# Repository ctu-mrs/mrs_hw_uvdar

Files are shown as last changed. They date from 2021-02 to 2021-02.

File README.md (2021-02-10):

# UVDAR Hardware
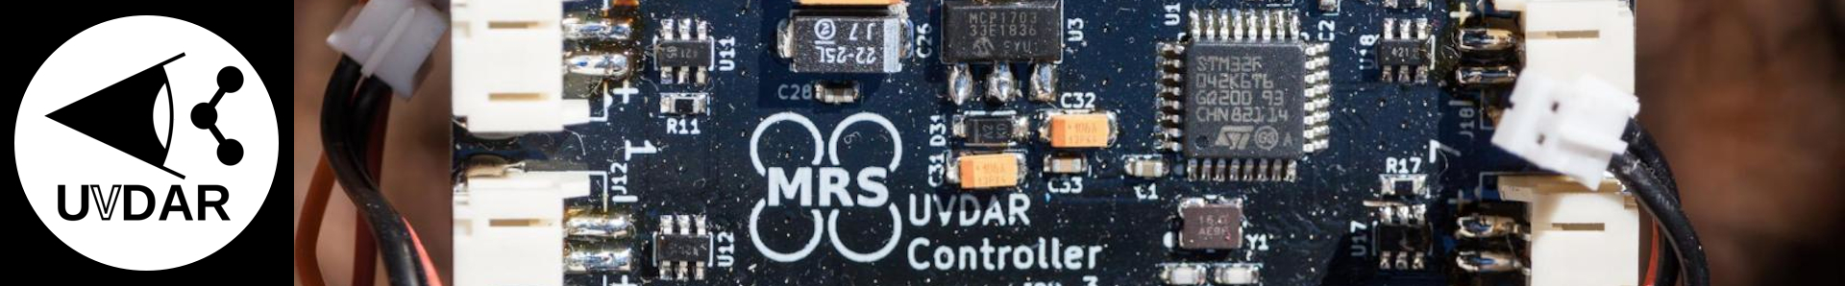
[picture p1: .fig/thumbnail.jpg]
thumbnail


## Description
This package contains hardware for UVDAR.<br>
[UVDAR](https://github.com/ctu-mrs/uvdar_core) Hardware is available in two variants: standalone and as MRS Module.<br>

The standalone variant can be connected to a computer directly using USB and is intended for quick development and trying out UVDAR.<br>
The MRS Module variant is intended to be used along with MRS Distribution Boards, namely with F450 Distribution Board as this is so far the
only Distribution board populated with a slot for a Big MRS Module.

<table>
  <tr>
    <th>
      UVDAR Standalone Variant
    </th>
    <th>
      UVDAR Module Variant
    </th>
  </tr>
  <tr>
    <td>
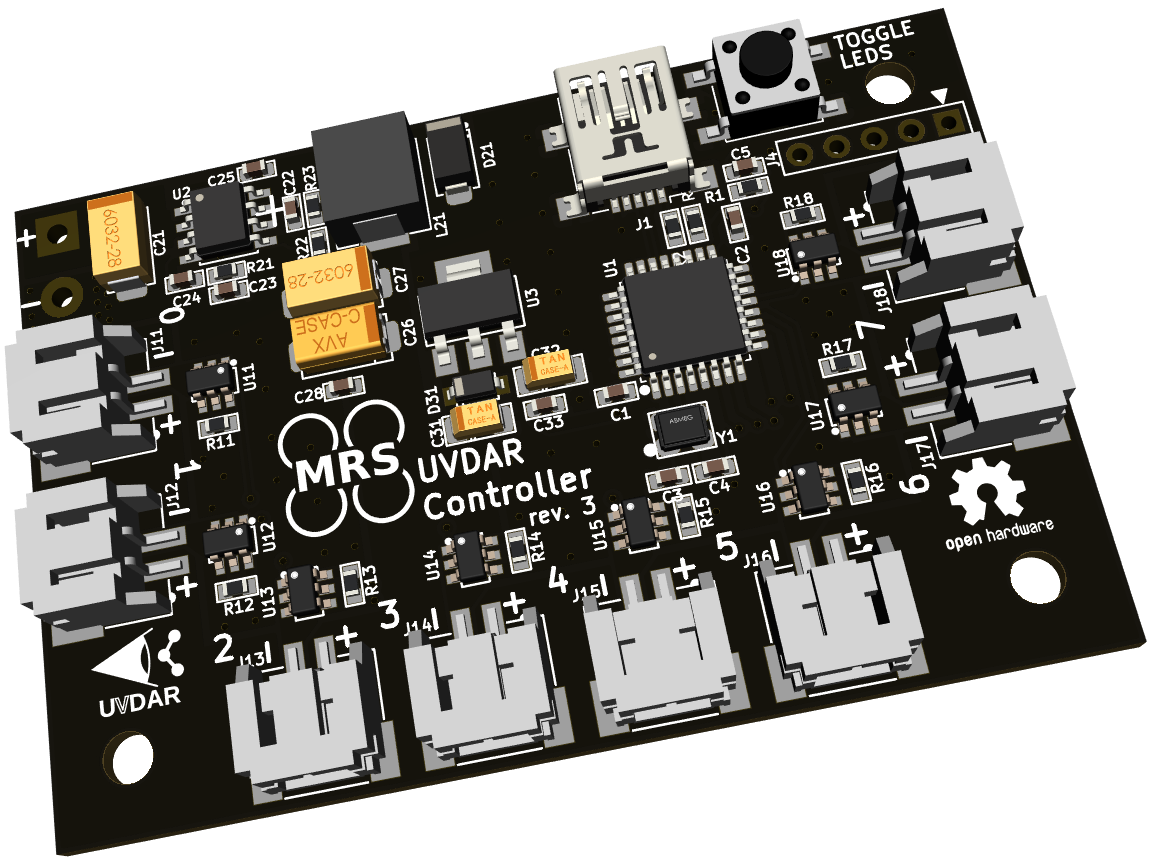
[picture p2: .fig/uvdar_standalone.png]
uvdar_standalone
      
    </td>
    <td>
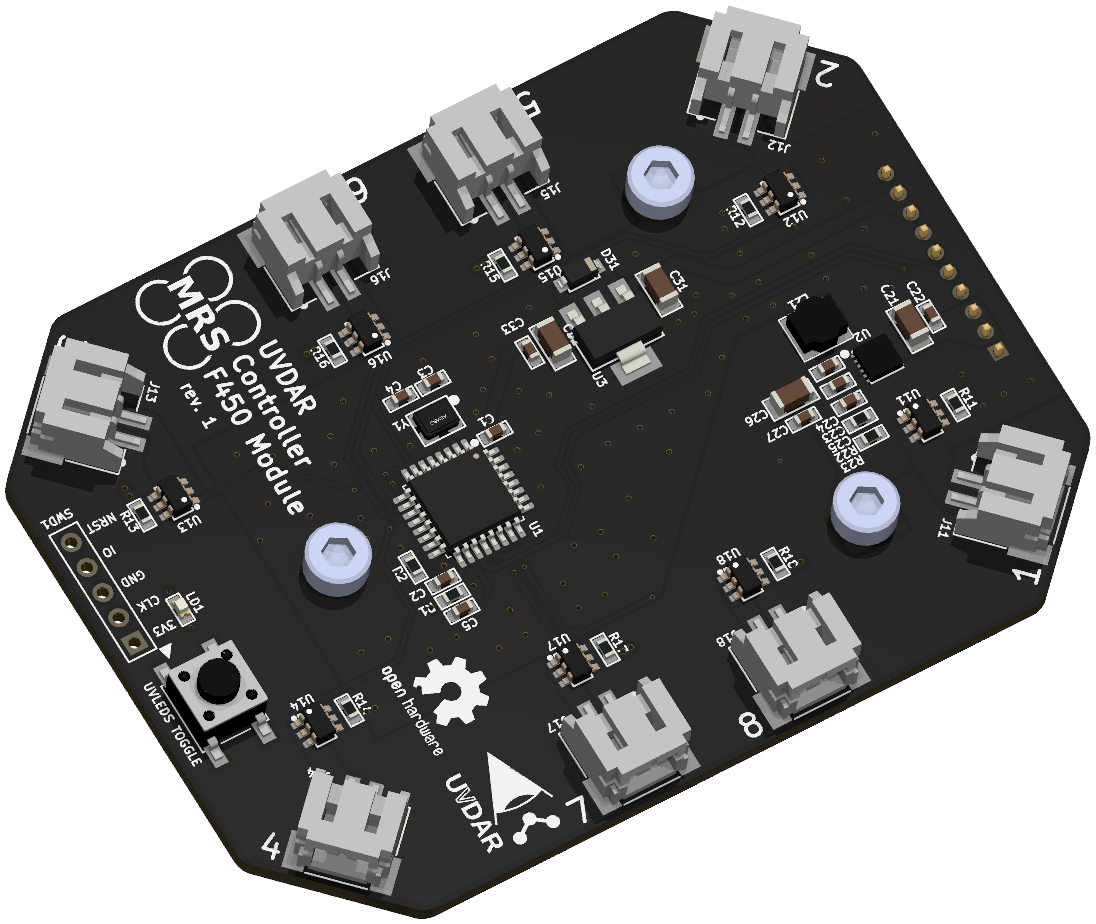
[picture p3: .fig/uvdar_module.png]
uvdar_module
      
    </td>
  </tr>
</table>

## How to use
1) Read the documentation provided with each variant.
2) Select which variant suits your needs better (note that you can use MRS Module Host Board for development with MRS Module variant).
3) Manufacture and assemble the PCB of the controller and the UV LEDs. The Gerber files as well as BOM is in the PCB folder of each variant.
4) Flash the control board with appropriate firmware using STM32CubeIDE, Atollic TrueSTUDIO, Keil uVision or STM32CubePRogrammer or any other software you like to use.
5) Connect the controller to a computer and use the [UVDAR ROS Package](https://github.com/ctu-mrs/uvdar_core).

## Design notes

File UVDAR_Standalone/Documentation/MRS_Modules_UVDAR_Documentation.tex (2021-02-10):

\documentclass[12pt, a4paper]{article}

\usepackage[export]{adjustbox}
\usepackage{fancyhdr}
\usepackage[utf8]{inputenc}
\usepackage[english]{babel}
\usepackage{longtable}
\usepackage[margin=2cm, bottom=4cm]{geometry}
\usepackage{color,soul}
\usepackage{booktabs}
\usepackage{pdfpages}

\pagestyle{fancy}
\fancyhf{}% Clear all headers/footers
\renewcommand{\headrulewidth}{.4pt}% Header rule width
\renewcommand{\footrulewidth}{0pt}% No footer rule
\fancyhead[L]{% Left header
  \rule[-1\baselineskip]{0pt}{0pt}% Strut to ensure a 1/4 \baselineskip between image and header rule
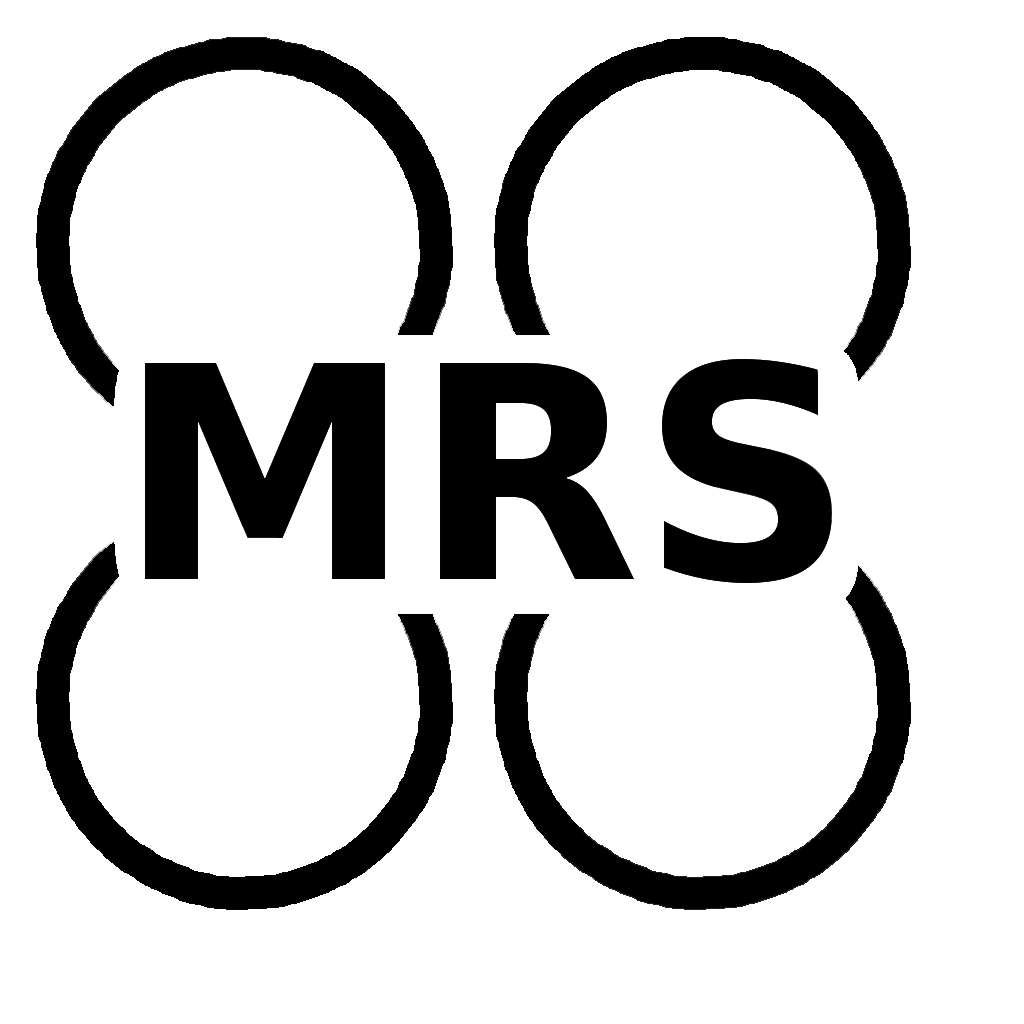
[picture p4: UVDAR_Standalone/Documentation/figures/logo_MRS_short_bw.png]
  % Image
  \quad% Space
}

\fancyhead[R]{
STANDALONE UVDAR CONTROLLER
}

\chead{\thepage}

\title{
\Huge{STANDALONE UVDAR CONTROLLER}\\
REVISION 3\\
\vspace{0.5cm}
\LARGE{David Zaitlik}\\
\vspace{0.5cm}
\normalsize{\textit{Multi-Robot Systems Group, FEE CTU in Prague}}\\
\vspace{1.5cm}
\vfill
\begin{figure}[h]
\centering
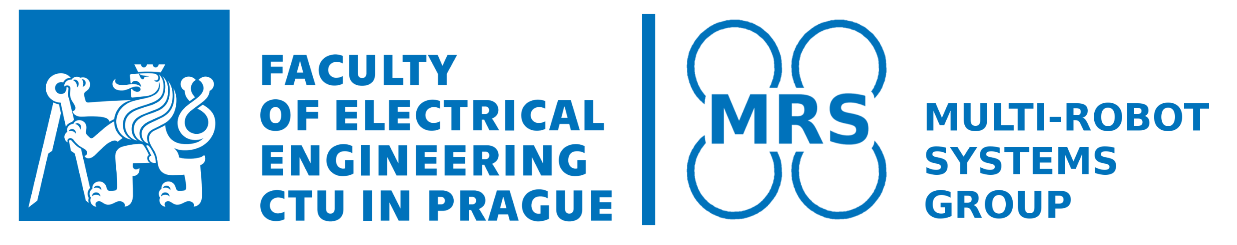
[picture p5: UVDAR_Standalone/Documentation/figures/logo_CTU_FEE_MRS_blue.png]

\end{figure}
\date{\today}

}

\setlength{\headheight}{3.5\baselineskip}% To accommodate new oversized header

\begin{document}
\clearpage
\maketitle
\thispagestyle{empty}

\pagebreak
\tableofcontents
\listoffigures
\listoftables
\thispagestyle{empty}

\pagebreak
\setcounter{page}{1}
\pagenumbering{arabic}
\section{Introduction}
UVDAR is a system for mutual UAV localization using Ultra-Violet LED blinkers.\\
\\
This PCB is a standalone UVDAR controller designed for simple development of the UVDAR system.\\
\\
The controller communicates using USB. The power for the PCB is provided by the \verb|J3| connector.\\
\\
The Board is designed to work with high-power UVLEDs ProLight Opto PM2B-1LLE, however any other similar UVLED can be used.\\
\begin{figure}[h]
\centering

\caption{STANDALONE UVDAR CONTROLLER: Thumbnail}
\label{fig:thumbnail}
\end{figure}

\pagebreak
\subsection{Default Configuration}
The default configuration used by the MRS Group drives two UVLEDs ProLight Opto PM2B-1LLE per channel. These UVLEDs are soldered to a PCB which acts as a heatsink and mounting point to the end of the drone arm. The UVLEDs are at a right angle, which can be seen in figure \ref{fig:f450_with_uvdar}.\\\
\\
The voltage for UVLEDs is set to 8V, but this can be easily changed by adjusting the value of $R_{22}$ resistor according to the following formula:\\
$R_{22} = 22.1 \cdot \left(V_{OUT} - 1 \right) \left[ k\Omega \right]$
\\
The UVLEDs are driven using constant-current controllers that are set to approximately to 85mA. This value can be modified by changing the value of resistors $R_{11} - R_{18}$ according to the BCR421UW6 driver datasheet.\\
\\
Channels 1-4 are used to drive the UVLEDs on the arms and channels 5-8 are used to drive the beacon UVLEDs on the top of the drone.

\begin{figure}[h]
\centering
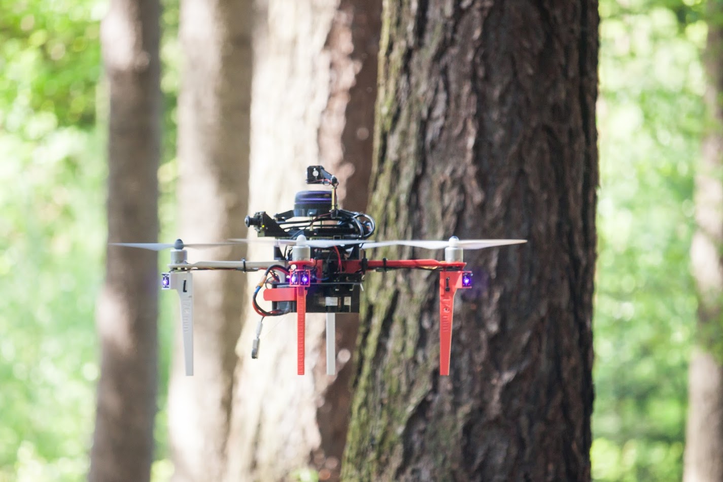
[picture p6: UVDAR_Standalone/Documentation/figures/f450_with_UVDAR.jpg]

\caption{STANDALONE UVDAR CONTROLLER: Photo of an F450 drone with UVDAR}
\label{fig:f450_with_uvdar}
\end{figure}

\pagebreak
\section{Dimensions}
The Board is 67mm long and 45mm wide with three M3 mounting holes.\\
\\
The mechanical drawing can be seen in Figure \ref{fig:dimensions} below.

\begin{figure}[h]
\centering

\caption{STANDALONE UVDAR CONTROLLER: Dimensions}
\label{fig:dimensions}
\end{figure}

\pagebreak
\section{Connectors}
The Board has 8 connectors numbered from 1 to 8 to connect UVLEDs. The pinout of these connectors is described in \verb|UVLED|.\\
The board has a connector for connecting to a Distribution Board with a standard pinout as seen in \verb|MRS MODULE|.\\
The last connector is the Serial Wire Debug (\verb|SWD|) connector for programming the on-board STM32F042K6T.
The connector placement can be seen in figures \ref{fig:connectors_top} and \ref{fig:connectors_bot}.
\subsection{Connector Placement Drawing}
\begin{figure}[h]
\centering

\caption{STANDALONE UVDAR CONTROLLER: Connectors Placement, Top Layer}
\label{fig:connectors_top}
\end{figure}

\pagebreak
\subsection{Connector Pinouts}
\begin{center}
\begin{minipage}[t][3cm][t]{0.24\textwidth}
\centering
\begin{tabular}{|l|l|}
\hline
\multicolumn{2}{|p{2cm}|}{\centering\textbf{UVLED}} \\ \hline
1               & LED ANODE                \\ \hline
2               & LED KATHODE                \\ \hline
\end{tabular}
\end{minipage}
\begin{minipage}[t][3cm][t]{0.24\textwidth}
\centering
\begin{tabular}{|l|l|}
\hline
\multicolumn{2}{|p{2cm}|}{\centering\textbf{BAT IN}} \\ \hline
1               & BAT+                \\ \hline
2               & BAT-                 \\ \hline
\end{tabular}
\end{minipage}

\begin{minipage}[t][3.5cm][t]{0.24\textwidth}
\centering
\begin{tabular}{|l|l|}
\hline
\multicolumn{2}{|p{3cm}|}{\centering\textbf{USB}} \\ \hline
1               & VUSB         \\ \hline
2               & D-        \\ \hline
3               & D+        \\ \hline
4               & NC         \\ \hline
5               & GND     \\ \hline
\end{tabular}
\end{minipage}
\begin{minipage}[t][3cm][t]{0.24\textwidth}
\centering
\begin{tabular}{|l|l|}
\hline
\multicolumn{2}{|p{2cm}|}{\centering\textbf{SWD}} \\ \hline
1               & 3V3               \\ \hline
2               & SWCLK             \\ \hline
3               & GND               \\ \hline
4               & SWDIO             \\ \hline
5               & NRST              \\ \hline
\end{tabular}
\hfill
\end{minipage}

\begin{minipage}[t][3.5cm][t]{0.24\textwidth}
\centering
\begin{tabular}{|l|l|}
\hline
\multicolumn{2}{|p{3cm}|}{\centering\textbf{MRS MODULE}} \\ \hline
1               & GND         \\ \hline
2               & VBAT        \\ \hline
3               & VBAT        \\ \hline
4               & GND         \\ \hline
5               & UART\verb|_|TX     \\ \hline
6               & UART\verb|_|RX     \\ \hline
7               & GND         \\ \hline
8               & 5V          \\ \hline
9               & 5V          \\ \hline
10              & GND         \\ \hline
\end{tabular}
\end{minipage}
\end{center}

\pagebreak
\section{MCU Firmware}

The firmware receives data using USB; the data are in the \verb|baca_protocol| format used by the \verb|mrs_serial| node.\\
The button on the PCB serves to "mute" the UVLEDs. This button toggles global enable flag in order to stop the blinking, but does not change any other settings and does not stop the counter. This flag can be set using the UART as well.\\
\\
All setting are stored in the internal FLASH memory and are retrieved on startup.\\
\\
The byte structure of the \verb|baca_protocol| can be seen in table \ref{tab:baca_protocol_table}.
The message starts with letter 'b' (0x62 in hex) and is followed by the length of the payload (1-255).
The payload then follows. The first byte of the payload is the \verb|Message ID| and the rest of the payload contains the data (if any). The last byte is the checksum which is a simple sum of all previous bytes.\\
\\
Several message types have been implemented to control the board.

\begin{table}[h]
\begin{tabular}{|c|c|c|c|c|c|}
\hline
\textbf{Byte}   & 0          & 1                     & 2 ... (n-1) & n        \\ \hline
\textbf{Value} & 'b' (0x62) & Length of the payload & Payload (Message ID and Data)       & Checksum \\ \hline
\end{tabular}
\caption{STANDALONE UVDAR CONTROLLER: Baca Protocol Message}
\label{tab:baca_protocol_table}
\end{table}

\subsection{Message Types}
The available messages are described below:\\
\begin{itemize}
\item \textbf{Global Enable LEDs} - This is a software version of the HW switch on the PCB - This overrides, but saves all configuration and turns off all UVLEDs, or resumes the original settings.\\
\begin{flushleft}
\begin{tabular}{|l|}
\hline
Command Byte: 0x90													\\ \hline
Payload Size: 0														\\ \hline
\end{tabular}
\end{flushleft}

\item \textbf{Bulk Enable LEDs} - Enables or Disables the UVLED with the same index as the payload Byte. This will reset counters of all LEDs.\\
\begin{flushleft}
\begin{tabular}{|l|}
\hline
Command Byte: 0x91													\\ \hline
Payload size: 8 B													\\ \hline
Payload Bytes: 0x00 (UVLED Disabled), 0x01 (UVLED Enabled)			\\ \hline
Payload Byte 0: UVLED1 enabled =  0x00 (Disabled), 0x01 (Enabled)	\\ \hline
Payload Byte 1: UVLED2 enabled =  0x00 (Disabled), 0x01 (Enabled)	\\ \hline
Payload Byte 2: UVLED3 enabled =  0x00 (Disabled), 0x01 (Enabled)	\\ \hline
Payload Byte 3: UVLED4 enabled =  0x00 (Disabled), 0x01 (Enabled)	\\ \hline
Payload Byte 4: UVLED5 enabled =  0x00 (Disabled), 0x01 (Enabled)	\\ \hline
Payload Byte 5: UVLED6 enabled =  0x00 (Disabled), 0x01 (Enabled)	\\ \hline
Payload Byte 6: UVLED7 enabled =  0x00 (Disabled), 0x01 (Enabled)	\\ \hline
Payload Byte 7: UVLED8 enabled =  0x00 (Disabled), 0x01 (Enabled)	\\ \hline
\end{tabular}
\end{flushleft}

\item \textbf{Bulk Set Periods} - Sets blinking freqeuncy of the LED with the same index as the payload Byte. This will reset counters of all LEDs.\\
\begin{flushleft}
\begin{tabular}{|l|}
\hline
Command Byte: 0x92													\\ \hline
Payload size: 8 B													\\ \hline
Payload Byte 0: Desired frequency of the UVLED1						\\ \hline
Payload Byte 1: Desired frequency of the UVLED2						\\ \hline
Payload Byte 2: Desired frequency of the UVLED3						\\ \hline
Payload Byte 3: Desired frequency of the UVLED4						\\ \hline
Payload Byte 4: Desired frequency of the UVLED5						\\ \hline
Payload Byte 5: Desired frequency of the UVLED6						\\ \hline
Payload Byte 6: Desired frequency of the UVLED7						\\ \hline
Payload Byte 7: Desired frequency of the UVLED8						\\ \hline
\end{tabular}
\end{flushleft}

\item \textbf{Enable LED} - enables the UVLED with the specified index. This will reset the counter of the specified UVLED.\\
\begin{flushleft}
\begin{tabular}{|l|}
\hline
Command Byte: 0x93													\\ \hline
Payload Size: 2														\\ \hline
Payload Byte 0: UVLED index (0-7)									\\ \hline
Payload Byte 1: 0x00 (Disabled), 0x01 (Enabled)						\\ \hline
\end{tabular}
\end{flushleft}

\item \textbf{Set Period} - Sets blinking frequency of the UVLED with the specified index. This will reset the counter of the specified UVLED.\\
\begin{flushleft}
\begin{tabular}{|l|}
\hline
Command Byte: 0x94													\\ \hline
Payload Size: 2														\\ \hline
Payload Byte 0: LED index (0-7)										\\ \hline
Payload Byte 1: Desired frequency of the UVLED						\\ \hline
\end{tabular}
\end{flushleft}

\item \textbf{Get Enabled} - Returns 8 bytes. These bytes indicate if the UVLEDs are enabled or disabled.\\
\begin{flushleft}
\begin{tabular}{|l|}
\hline
Command Byte: 0x95															\\ \hline
Payload Size: 0																\\ \hline
Return Payload Size: 8														\\ \hline
Return Payload Byte 0: UVLED1 enabled =  0x00 (Disabled), 0x01 (Enabled)	\\ \hline
Return Payload Byte 1: UVLED2 enabled =  0x00 (Disabled), 0x01 (Enabled)	\\ \hline
Return Payload Byte 2: UVLED3 enabled =  0x00 (Disabled), 0x01 (Enabled)	\\ \hline
Return Payload Byte 3: UVLED4 enabled =  0x00 (Disabled), 0x01 (Enabled)	\\ \hline
Return Payload Byte 4: UVLED5 enabled =  0x00 (Disabled), 0x01 (Enabled)	\\ \hline
Return Payload Byte 5: UVLED6 enabled =  0x00 (Disabled), 0x01 (Enabled)	\\ \hline
Return Payload Byte 6: UVLED7 enabled =  0x00 (Disabled), 0x01 (Enabled)	\\ \hline
Return Payload Byte 7: UVLED8 enabled =  0x00 (Disabled), 0x01 (Enabled)	\\ \hline
\end{tabular}
\end{flushleft}

\item \textbf{Get Periods} - Returns 8 bytes. These bytes represent the frequency of the UVLEDs.\\
\begin{flushleft}
\begin{tabular}{|l|}
\hline
Command Byte: 0x96														\\ \hline
Payload Size: 0															\\ \hline
Return Payload Size: 8													\\ \hline
Return Payload Byte 0: UVLED1 Frequency									\\ \hline
Return Payload Byte 1: UVLED2 Frequency									\\ \hline
Return Payload Byte 2: UVLED3 Frequency									\\ \hline
Return Payload Byte 3: UVLED4 Frequency									\\ \hline
Return Payload Byte 4: UVLED5 Frequency									\\ \hline
Return Payload Byte 5: UVLED6 Frequency									\\ \hline
Return Payload Byte 6: UVLED7 Frequency									\\ \hline
Return Payload Byte 7: UVLED8 Frequency									\\ \hline
\end{tabular}
\end{flushleft}
\end{itemize}
\pagebreak
\subsection{Implementation notes}
The Board is equipped with the STM32F042K6T6 microcontroller. Its firmware is programmed using STM32Cube Hardware Abstraction Layer Libraries.\\
The pinout of the MCU can be seen in the Figure \ref{fig:ph_mcu_pinout}.\\
\begin{figure}[h]
\centering
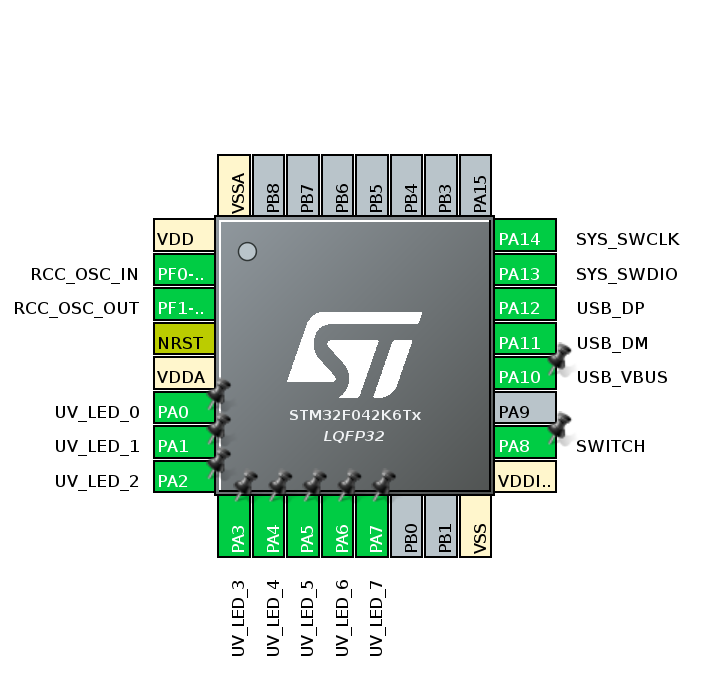
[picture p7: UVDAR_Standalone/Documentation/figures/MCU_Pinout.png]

\caption{STANDALONE UVDAR CONTROLLER: MCU pinout}
\label{fig:mcu_pinout}
\end{figure}
The firmware is written with the need for versatility in mind and therefore is not optimal for specialised applications. The UVLED blinking is implemented using software PWM which allows us to change frequencies of individual channels, as is desired for research purposes. I suggest using hardware PWMs if the UVLEDs will have the same frequency. This is achievable only for UVLEDs 1 to 4 since these are connected to TIM2 channels 1 to 4. The other UVLED channels were moved to arbitrary pins for easier routing in the beginning and were left for legacy purposes. If hardware PWM for all channels is desired, then rearanging UVLEDs is necessary.

\pagebreak
\subsection{Software PWM for UVLEDs}
The UVLED blinking is implemented in \verb|uv_led_driver.c/h| files. To function properly, the pins must be named as \verb|UV_LED_x| where \verb|x| is a number between 0 and 8. This may of course be be changed by the programmer. These pins are used in the \verb|uv_led_init( void )| function to map them to an internally used array. This function also reads the frequency values and flags for enabling UVLEDs from the internal FLASH and resets the counters.\\
\\
The \verb|uv_led_set_frequency(uint8_t led_id, uint8_t frequency)| function sets the frequency of the selected UVLED. The input argument \verb|led_id| is index of the UVLED to be set starting from 0 and the \verb|frequency| is an integer value of desired frequency in range 1 to 60 Hz.\\
This function then calculates the number of ticks of the counter needed to toggle the LED (half of its total period). To calculate this value properly, the value of \verb|TIMER_FREQ| must be set to the frequency of the hardware timer used to increment the counter.\\
The calculated value is then saved to the internal FLASH.\\
\\
The \verb|uv_led_enable(uint8_t led_id, uint8_t enable)| function sets the enable flag of the selected UVLED. The input argument \verb|led_id| is index of the UVLED to be set starting from 0, with \verb|enable| as an integer of value 1 (true) or 0(false). Any other values are invalid.\\
The enable flag is then saved to the internal FLASH.\\
\\
The \verb|uv_led_toggle(uint8_t led_id)| function toggles the selected UVLED. The input argument \verb|led_id| is index of the UVLED to be set starting from 0.\\
This function is called if the counter value reaches the desired value. This is managed using the Timer Period Elapsed Callback Function \verb|HAL_TIM_PeriodElapsedCallback| where the counter is increased everytime the used timer's period elapses. The used timer in this appliation is \verb|TIM3| with a frequency of 10kHz.
\subsubsection{Global Enable Flag}
To be able to disable all UVLEDs on a button switch without affecting anything else, a simple flag was created. This flag toggles on with a button press (\verb|SWITCH|) or with receiving a global enable message using UART. This flag is used in the \verb|uv_led_toggle(uint8_t led_id)|.

\subsection{USB implementation}
TODO: Rewrite to USB
The USB communication using the STM Middleware. The message is processed in \verb|CDC_Receive_FS| function in \verb|usbd_cdc_if.c| file. If the message has the correct format (if the checksum is correct and has one of the valid message IDs), the apropriate function is called.\\
\\ VBUS Sensing has not yet been implemented.
\pagebreak

\newgeometry{left=1cm,right=1cm}
\section{Bill Of Materials and Assembly Drawings}
\begin{longtable}{|p{5cm}|p{5cm}|p{5cm}|p{1.7cm}|}
\hline
\textbf{References} & \textbf{Value} & \textbf{Footprint} & \textbf{Quantity}\\ \hline
C2, C5, C25, C33                       & 0.1uF                   & C0603                                      & 4        \\ \hline
C3, C4, C22                            & 10pF                    & C0603                                      & 3        \\ \hline
C1, C28                                & 1uF                     & C0603                                      & 2        \\ \hline
C23                                    & 1nF                     & C0603                                      & 1        \\ \hline
C24                                    & 10nF                    & C0603                                      & 1        \\ \hline
C31, C32                               & 10uF                    & CTAN1206                                   & 2        \\ \hline
C26                                    & 100uF/10V               & CTAN2312                                   & 1        \\ \hline
C21, C27                               & 22uF/25V                & CTAN2412                                   & 2        \\ \hline
R11, R12, R13, R14, R15, R16, R17, R18 & 3R3-0.5\%               & R0603                                      & 8        \\ \hline
R1, R2, R3, R22                        & 10k                     & R0603                                      & 4        \\ \hline
R21                                    & 27k4                    & R0603                                      & 1        \\ \hline
R23                                    & 1k1                     & R0603                                      & 1        \\ \hline
L21                                    & SRP6540-8R2M            & L\_SRP6540                                 & 1        \\ \hline
D21                                    & B340A                   & D\_SMA                                     & 1        \\ \hline
D31                                    & 1N4148W-E3-08           & SOD-123                                    & 1        \\ \hline
U1                                     & STM32F042K6T6           & LQFP-32\_7x7mm\_P0.8mm                     & 1        \\ \hline
U2                                     & TPS54331DR              & SOIC-8                                     & 1        \\ \hline
U3                                     & MCP1703-3302E           & SOT-223-3(TAB-pin-2)                       & 1        \\ \hline
U11, U12, U13, U14, U15, U16, U17, U18 & BCR421UW6               & SOT-26-6                                   & 8        \\ \hline
Y1                                     & ABM8G                   & ABM8G                                      & 1        \\ \hline
SW1                                    & Push-Switch\_SMT\_6x6mm & Tactile\_Switch\_6x6\_SMT                  & 1        \\ \hline
J4                                     & SWO                     & Header\_1x05\_P2.54mm                      & 1        \\ \hline
J11, J12, J13, J14, J15, J16, J17, J18 & JST-PH\_2               & JST\_PH\_2                                 & 8        \\ \hline
J1                                     & USB\_B\_Mini            & USB\_Mini-B\_Lumberg\_2486\_01\_Horizontal & 1        \\ \hline

\caption{STANDALONE UVDAR CONTROLLER: Bill Of Materials}
\label{tab:bom}
\end{longtable}
\vfill
\restoregeometry

\pagebreak
% change scale and angle accordingly
\includepdf[pages=-, scale=0.8, angle=270, pagecommand={}]{figures/Assembly_top.pdf}

\pagebreak
\section{Schematic}


\end{document}

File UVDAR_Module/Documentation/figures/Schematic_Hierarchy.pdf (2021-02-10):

MAIN SHEET

Sheet 1

BUCK 8V

Sheet 2

8V

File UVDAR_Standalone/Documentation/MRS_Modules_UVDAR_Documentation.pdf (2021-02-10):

# STANDALONE UVDAR CONTROLLER REVISION 3

# David Zaitlik

Multi-Robot Systems Group, FEE CTU in Prague

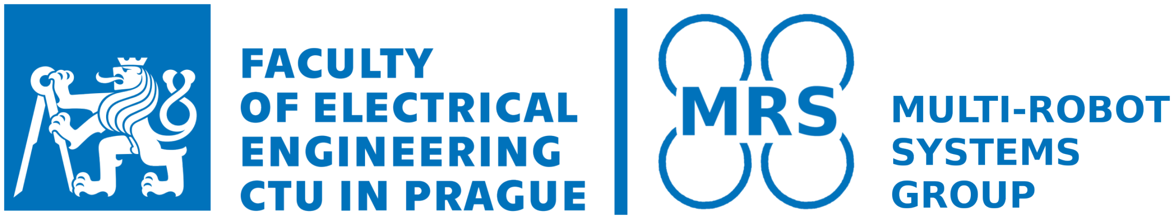
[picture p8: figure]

### February 10, 2021

## Contents

1 Introduction | 1
1.1 Default Configuration | | 2
2 Dimensions | 3
3 Connectors | 4
3.1 Connector Placement Drawing | | 4
3.2 Connector Pinouts | | 5
4 MCU Firmware | 6
4.1 Message Types | | 6
4.2 Implementation notes | | 9
4.3 Software PWM for UVLEDs | 10
4.3.1 Global Enable Flag | 10
4.4 USB implementation | 10
5 Bill Of Materials and Assembly Drawings | 11
6 Schematic | 13

## List of Figures

1 | STANDALONE UVDAR CONTROLLER: Thumbnail | | 1
2 | STANDALONE UVDAR CONTROLLER: Photo of an F450 drone with UVDAR 2
3 | STANDALONE UVDAR CONTROLLER: Dimensions | | 3
4 | STANDALONE UVDAR CONTROLLER: Connectors Placement, Top Layer . . | 4
5 | STANDALONE UVDAR CONTROLLER: MCU pinout | | 9

## List of Tables

1 | STANDALONE UVDAR CONTROLLER: Baca Protocol Message | | 6
2 | STANDALONE UVDAR CONTROLLER: Bill Of Materials | 11

1 STANDALONE UVDAR CONTROLLER

## 1 Introduction

UVDAR is a system for mutual UAV localization using Ultra-Violet LED blinkers.

This PCB is a standalone UVDAR controller designed for simple development of the UVDAR system.

The controller communicates using USB. The power for the PCB is provided by the J3 connector.

The Board is designed to work with high-power UVLEDs ProLight Opto PM2B-1LLE, however any other similar UVLED can be used.

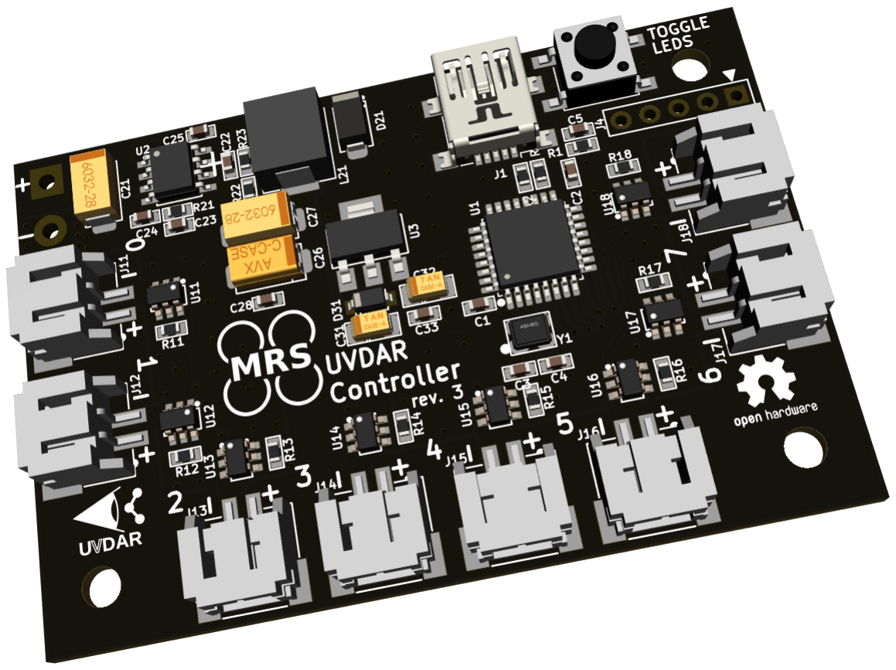
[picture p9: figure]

Figure 1: STANDALONE UVDAR CONTROLLER: Thumbnail

### 1.1 Default Configuration

The default configuration used by the MRS Group drives two UVLEDs ProLight Opto PM2B-1LLE per channel. These UVLEDs are soldered to a PCB which acts as a heatsink and mounting point to the end of the drone arm. The UVLEDs are at a right angle, which can be seen in figure 2.

The voltage for UVLEDs is set to 8V, but this can be easily changed by adjusting the value of R22 resistor according to the following formula:
R22 = 22.1 · (VOUT − 1) [kΩ]
The UVLEDs are driven using constant-current controllers that are set to approximately to 85mA. This value can be modified by changing the value of resistors R11 − R18 according to the BCR421UW6 driver datasheet.

Channels 1-4 are used to drive the UVLEDs on the arms and channels 5-8 are used to drive the beacon UVLEDs on the top of the drone.


Figure 2: STANDALONE UVDAR CONTROLLER: Photo of an F450 drone with UVDAR

## 2 Dimensions

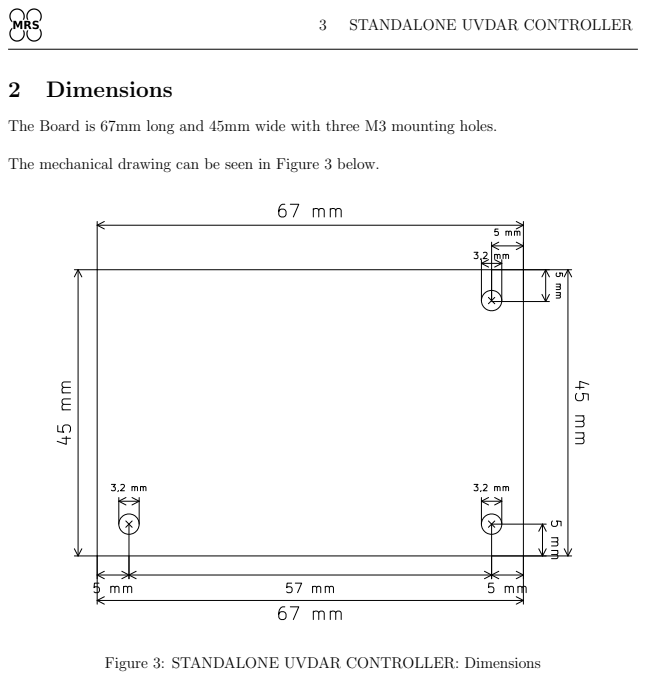
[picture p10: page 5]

The Board is 67mm long and 45mm wide with three M3 mounting holes.

The mechanical drawing can be seen in Figure 3 below.

Figure 3: STANDALONE UVDAR CONTROLLER: Dimensions

## 3 Connectors

The Board has 8 connectors numbered from 1 to 8 to connect UVLEDs. The pinout of these connectors is described in UVLED.
The board has a connector for connecting to a Distribution Board with a standard pinout as seen in MRS MODULE.
The last connector is the Serial Wire Debug (SWD) connector for programming the on-board STM32F042K6T. The connector placement can be seen in figures 4 and ??.

### 3.1 Connector Placement Drawing

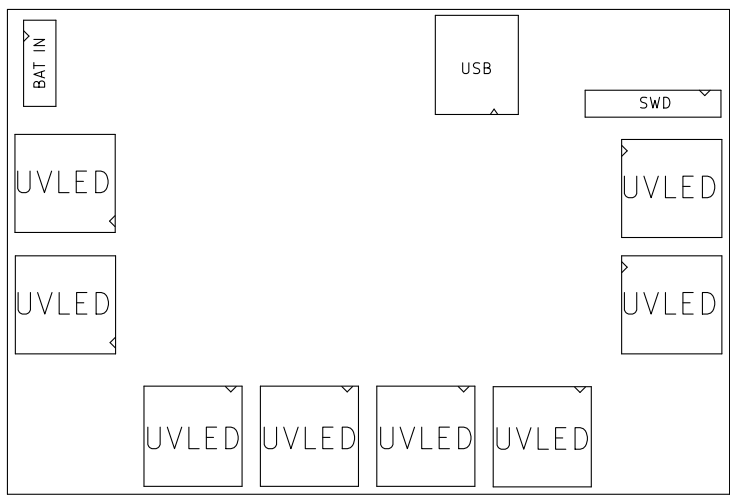
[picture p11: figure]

Figure 4: STANDALONE UVDAR CONTROLLER: Connectors Placement, Top Layer

### 3.2 Connector Pinouts

UVLED
1 | LED ANODE
2 | LED KATHODE

BAT IN
1 | BAT+
2 | BAT-

USB
1 | VUSB
2 | D-
3 | D+
4 | NC
5 | GND

SWD
1 | 3V3
2 | SWCLK
3 | GND
4 | SWDIO
5 | NRST

MRS
MODULE
1 | GND
2 | VBAT
3 | VBAT
4 | GND
5 | UART_TX
6 | UART_RX
7 | GND
8 | 5V
9 | 5V
10 | GND

## 4 MCU Firmware

The firmware receives data using USB; the data are in the baca_protocol format used by the mrs_serial node.
The button on the PCB serves to ”mute” the UVLEDs. This button toggles global enable flag in order to stop the blinking, but does not change any other settings and does not stop the counter. This flag can be set using the UART as well.

All setting are stored in the internal FLASH memory and are retrieved on startup.

The byte structure of the baca_protocol can be seen in table 1. The message starts with letter ’b’ (0x62 in hex) and is followed by the length of the payload (1-255). The payload then follows. The first byte of the payload is the Message ID and the rest of the payload contains the data (if any). The last byte is the checksum which is a simple sum of all previous bytes.

Several message types have been implemented to control the board.

Byte | 0 | 1 | 2 ... (n-1) | n
Value | ’b’ (0x62) | Length of the payload | Payload (Message ID and Data) | Checksum

Table 1: STANDALONE UVDAR CONTROLLER: Baca Protocol Message

### 4.1 Message Types

The available messages are described below:

Global Enable LEDs - This is a software version of the HW switch on the PCB - This overrides, but saves all configuration and turns off all UVLEDs, or resumes the original settings.

Command Byte: 0x90
Payload Size: 0

Bulk Enable LEDs - Enables or Disables the UVLED with the same index as the pay- load Byte. This will reset counters of all LEDs.

Command Byte: 0x91
Payload size: 8 B
Payload Bytes: 0x00 (UVLED Disabled), 0x01 (UVLED Enabled) Payload Byte 0: UVLED1 enabled = 0x00 (Disabled), 0x01 (Enabled) Payload Byte 1: UVLED2 enabled = 0x00 (Disabled), 0x01 (Enabled) Payload Byte 2: UVLED3 enabled = 0x00 (Disabled), 0x01 (Enabled) Payload Byte 3: UVLED4 enabled = 0x00 (Disabled), 0x01 (Enabled) Payload Byte 4: UVLED5 enabled = 0x00 (Disabled), 0x01 (Enabled) Payload Byte 5: UVLED6 enabled = 0x00 (Disabled), 0x01 (Enabled) Payload Byte 6: UVLED7 enabled = 0x00 (Disabled), 0x01 (Enabled)
Payload Byte 7: UVLED8 enabled = 0x00 (Disabled), 0x01 (Enabled)

Bulk Set Periods - Sets blinking freqeuncy of the LED with the same index as the payload Byte. This will reset counters of all LEDs.

Command Byte: 0x92
Payload size: 8 B
Payload Byte 0: Desired frequency of the UVLED1 Payload Byte 1: Desired frequency of the UVLED2 Payload Byte 2: Desired frequency of the UVLED3 Payload Byte 3: Desired frequency of the UVLED4 Payload Byte 4: Desired frequency of the UVLED5 Payload Byte 5: Desired frequency of the UVLED6 Payload Byte 6: Desired frequency of the UVLED7
Payload Byte 7: Desired frequency of the UVLED8

Enable LED - enables the UVLED with the specified index. This will reset the counter of the specified UVLED.

Command Byte: 0x93
Payload Size: 2
Payload Byte 0: UVLED index (0-7)
Payload Byte 1: 0x00 (Disabled), 0x01 (Enabled)

Set Period - Sets blinking frequency of the UVLED with the specified index. This will reset the counter of the specified UVLED.

Command Byte: 0x94
Payload Size: 2
Payload Byte 0: LED index (0-7)
Payload Byte 1: Desired frequency of the UVLED

Get Enabled - Returns 8 bytes. These bytes indicate if the UVLEDs are enabled or disabled.

Command Byte: 0x95
Payload Size: 0
Return Payload Size: 8
Return Payload Byte 0: UVLED1 enabled = 0x00 (Disabled), 0x01 (Enabled) Return Payload Byte 1: UVLED2 enabled = 0x00 (Disabled), 0x01 (Enabled) Return Payload Byte 2: UVLED3 enabled = 0x00 (Disabled), 0x01 (Enabled) Return Payload Byte 3: UVLED4 enabled = 0x00 (Disabled), 0x01 (Enabled) Return Payload Byte 4: UVLED5 enabled = 0x00 (Disabled), 0x01 (Enabled) Return Payload Byte 5: UVLED6 enabled = 0x00 (Disabled), 0x01 (Enabled) Return Payload Byte 6: UVLED7 enabled = 0x00 (Disabled), 0x01 (Enabled) Return Payload Byte 7: UVLED8 enabled = 0x00 (Disabled), 0x01 (Enabled)

Get Periods - Returns 8 bytes. These bytes represent the frequency of the UVLEDs.

Command Byte: 0x96
Payload Size: 0
Return Payload Size: 8
Return Payload Byte 0: UVLED1 Frequency Return Payload Byte 1: UVLED2 Frequency Return Payload Byte 2: UVLED3 Frequency Return Payload Byte 3: UVLED4 Frequency Return Payload Byte 4: UVLED5 Frequency Return Payload Byte 5: UVLED6 Frequency Return Payload Byte 6: UVLED7 Frequency Return Payload Byte 7: UVLED8 Frequency

### 4.2 Implementation notes

The Board is equipped with the STM32F042K6T6 microcontroller. Its firmware is programmed using STM32Cube Hardware Abstraction Layer Libraries.
The pinout of the MCU can be seen in the Figure ??.
The firmware is written with the need for versatility in mind and therefore is not optimal


Figure 5: STANDALONE UVDAR CONTROLLER: MCU pinout

for specialised applications. The UVLED blinking is implemented using software PWM which allows us to change frequencies of individual channels, as is desired for research purposes. I suggest using hardware PWMs if the UVLEDs will have the same frequency. This is achievable only for UVLEDs 1 to 4 since these are connected to TIM2 channels 1 to 4. The other UVLED channels were moved to arbitrary pins for easier routing in the beginning and were left for legacy purposes. If hardware PWM for all channels is desired, then rearanging UVLEDs is necessary.

### 4.3 Software PWM for UVLEDs

The UVLED blinking is implemented in uv_led_driver.c/h files. To function properly, the pins must be named as UV_LED_x where x is a number between 0 and 8. This may of course be be changed by the programmer. These pins are used in the uv_led_init( void ) function to map them to an internally used array. This function also reads the frequency values and flags for enabling UVLEDs from the internal FLASH and resets the counters.

The uv_led_set_frequency(uint8_t led_id, uint8_t frequency) function sets the frequency of the selected UVLED. The input argument led_id is index of the UVLED to be set starting from 0 and the frequency is an integer value of desired frequency in range 1 to 60 Hz. This function then calculates the number of ticks of the counter needed to toggle the LED (half of its total period). To calculate this value properly, the value of TIMER_FREQ must be set to the frequency of the hardware timer used to increment the counter.
The calculated value is then saved to the internal FLASH.

The uv_led_enable(uint8_t led_id, uint8_t enable) function sets the enable flag of the selected UVLED. The input argument led_id is index of the UVLED to be set starting from 0, with enable as an integer of value 1 (true) or 0(false). Any other values are invalid.
The enable flag is then saved to the internal FLASH.

The uv_led_toggle(uint8_t led_id) function toggles the selected UVLED. The input argument led_id is index of the UVLED to be set starting from 0.
This function is called if the counter value reaches the desired value. This is managed using the Timer Period Elapsed Callback Function HAL_TIM_PeriodElapsedCallback where the counter is increased everytime the used timer’s period elapses. The used timer in this appliation is TIM3 with a frequency of 10kHz.

### 4.3.1 Global Enable Flag

To be able to disable all UVLEDs on a button switch without affecting anything else, a simple flag was created. This flag toggles on with a button press (SWITCH) or with receiving a global enable message using UART. This flag is used in the uv_led_toggle(uint8_t led_id).

### 4.4 USB implementation

TODO: Rewrite to USB The USB communication using the STM Middleware. The message is processed in CDC_Receive_FS function in usbd_cdc_if.c file. If the message has the correct format (if the checksum is correct and has one of the valid message IDs), the apropriate function is called.

VBUS Sensing has not yet been implemented.

## 5 Bill Of Materials and Assembly Drawings

References | Value | Footprint | Quantity
C2, C5, C25, C33 | 0.1uF | C0603 | 4
C3, C4, C22 | 10pF | C0603 | 3
C1, C28 | 1uF | C0603 | 2
C23 | 1nF | C0603 | 1
C24 | 10nF | C0603 | 1
C31, C32 | 10uF | CTAN1206 | 2
C26 | 100uF/10V | CTAN2312 | 1
C21, C27 | 22uF/25V | CTAN2412 | 2
R11, R12, R13, R14, R15, R16, R17, R18 | 3R3-0.5% | R0603 | 8
R1, R2, R3, R22 | 10k | R0603 | 4
R21 | 27k4 | R0603 | 1
R23 | 1k1 | R0603 | 1
L21 | SRP6540-8R2M | L SRP6540 | 1
D21 | B340A | D SMA | 1
D31 | 1N4148W-E3-08 | SOD-123 | 1
U1 | STM32F042K6T6 | LQFP-32 7x7mm P0.8mm | 1
U2 | TPS54331DR | SOIC-8 | 1
U3 | MCP1703-3302E | SOT-223-3(TAB-pin-2) | 1
U11, U12, U13, U14, U15, U16, U17, U18 | BCR421UW6 | SOT-26-6 | 8
Y1 | ABM8G | ABM8G | 1
SW1 | Push-Switch SMT 6x6mm | Tactile Switch 6x6 SMT | 1
J4 | SWO | Header 1x05 P2.54mm | 1
J11, J12, J13, J14, J15, J16, J17, J18 | JST-PH 2 | JST PH 2 | 8
J1 | USB B Mini | USB Mini-B Lumberg 2486 01 Horizontal | 1

Table 2: STANDALONE UVDAR CONTROLLER: Bill Of Materials

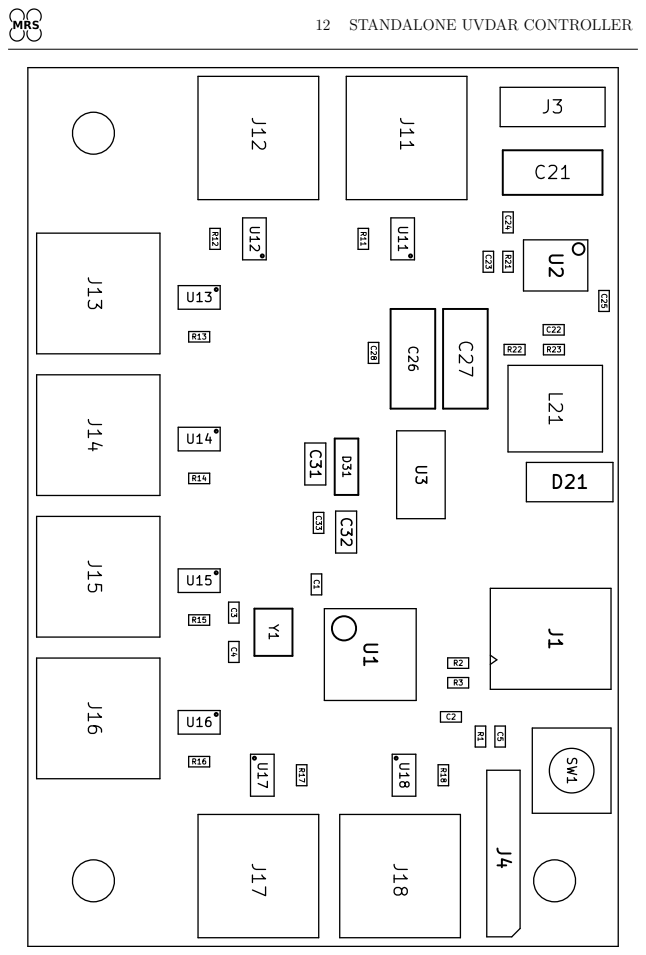
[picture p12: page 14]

## 6 Schematic

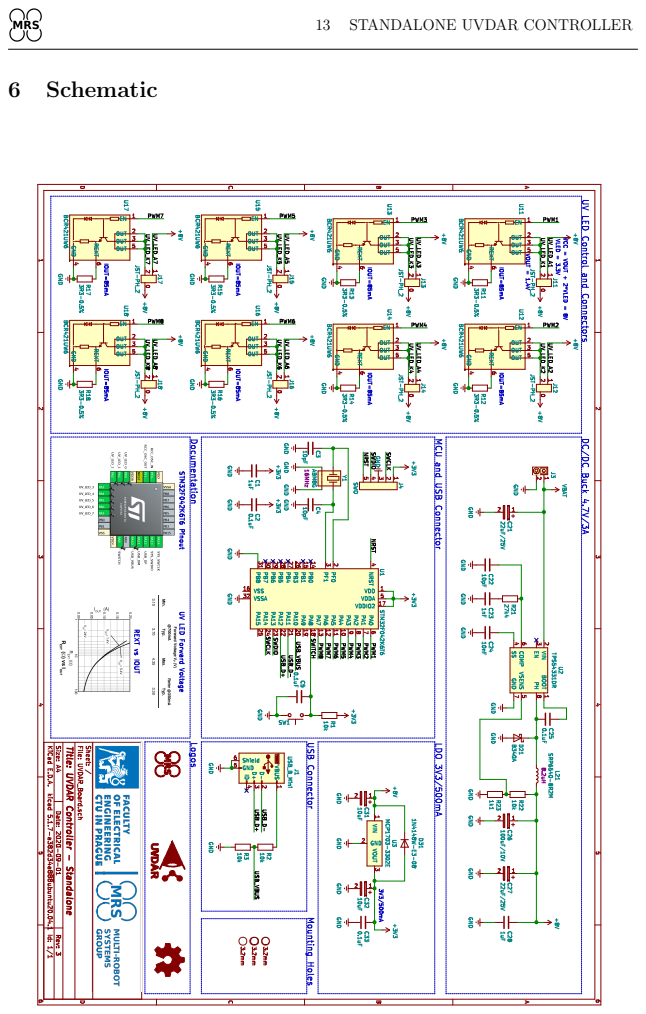
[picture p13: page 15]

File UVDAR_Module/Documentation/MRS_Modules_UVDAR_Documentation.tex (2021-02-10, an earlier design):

\documentclass[12pt, a4paper]{article}

\usepackage[export]{adjustbox}
\usepackage{fancyhdr}
\usepackage[utf8]{inputenc}
\usepackage[english]{babel}
\usepackage{longtable}
\usepackage[margin=2cm, bottom=4cm]{geometry}
\usepackage{color,soul}
\usepackage{booktabs}
\usepackage{pdfpages}

\pagestyle{fancy}
\fancyhf{}% Clear all headers/footers
\renewcommand{\headrulewidth}{.4pt}% Header rule width
\renewcommand{\footrulewidth}{0pt}% No footer rule
\fancyhead[L]{% Left header
  \rule[-1\baselineskip]{0pt}{0pt}% Strut to ensure a 1/4 \baselineskip between image and header rule
  % Image
  \quad% Space
}

\fancyhead[R]{
MRS MODULE - UVDAR
}

\chead{\thepage}

\title{
\Huge{MRS MODULE - UVDAR}\\
REVISION 1\\
\vspace{0.5cm}
\LARGE{David Zaitlik}\\
\vspace{0.5cm}
\normalsize{\textit{Multi-Robot Systems Group, FEE CTU in Prague}}\\
\vspace{1.5cm}
\vfill
\begin{figure}[h]
\centering

\end{figure}
\date{\today}

}

\setlength{\headheight}{3.5\baselineskip}% To accommodate new oversized header

\begin{document}
\clearpage
\maketitle
\thispagestyle{empty}

\pagebreak
\tableofcontents
\listoffigures
\listoftables
\thispagestyle{empty}

\pagebreak
\setcounter{page}{1}
\pagenumbering{arabic}
\section{Introduction}
UVDAR is a system for mutual UAV localization using Ultra-Violet LED blinkers.\\
\\
This PCB is an MRS Module providing UVDAR functionality to drones equipped by an MRS Distribution Board with a slot for a large MRS Module.\\
\\
This module communicates using UART. Both communication and power are provided from the used Distribution Board.\\
\\
The Board is designed to work with high-power UVLEDs ProLight Opto PM2B-1LLE, however any other similar UVLED can be used.\\
\begin{figure}[h]
\centering

\caption{MRS MODULE - UVDAR: Thumbnail}
\label{fig:thumbnail}
\end{figure}

\pagebreak
\subsection{Default Configuration}
The default configuration used by the MRS Group drives two UVLEDs ProLight Opto PM2B-1LLE per channel. These UVLEDs are soldered to a PCB which acts as a heatsink and mounting point to the end of the drone arm. The UVLEDs are at a right angle, which can be seen in figure \ref{fig:f450_with_uvdar}.\\\
\\
The voltage for UVLEDs is set to 8V, but this can be easily changed by adjusting the value of $R_{22}$ resistor according to the following formula:\\
$R_{22} = 22.1 \cdot \left(V_{OUT} - 1 \right) \left[ k\Omega \right]$
\\
The UVLEDs are driven using constant-current controllers that are set to approximately to 85mA. This value can be modified by changing the value of resistors $R_{11} - R_{18}$ according to the BCR421UW6 driver datasheet.\\
\\
Channels 1-4 are used to drive the UVLEDs on the arms and channels 5-8 are used to drive the beacon UVLEDs on the top of the drone.

\begin{figure}[h]
\centering

\caption{MRS MODULE - UVDAR: Photo of an F450 drone with UVDAR}
\label{fig:f450_with_uvdar}
\end{figure}

\pagebreak
\section{Dimensions}
The Board is 80mm long and 60mm wide with three M3 mounting holes.\\
\\
The mechanical drawing can be seen in Figure \ref{fig:dimensions} below.

\begin{figure}[h]
\centering

\caption{MRS MODULE - UVDAR: Dimensions}
\label{fig:dimensions}
\end{figure}

\pagebreak
\section{Connectors}
The Board has 8 connectors numbered from 1 to 8 to connect UVLEDs. The pinout of these connectors is described in \verb|UVLED|.\\
The board has a connector for connecting to a Distribution Board with a standard pinout as seen in \verb|MRS MODULE|.\\
The last connector is the Serial Wire Debug (\verb|SWD|) connector for programming the on-board STM32F042K6T.
The connector placement can be seen in figures \ref{fig:connectors_top} and \ref{fig:connectors_bot}.
\subsection{Connector Placement Drawing}
\begin{figure}[h]
\centering

\caption{MRS MODULE - UVDAR: Connectors Placement, Top Layer}
\label{fig:connectors_top}
\end{figure}

\begin{figure}[h]
\centering

\caption{MRS MODULE - UVDAR: Connectors Placement, Bottom Layer}
\label{fig:connectors_bot}
\end{figure}

\pagebreak
\subsection{Connector Pinouts}
\begin{center}
\begin{minipage}[t][3cm][t]{0.24\textwidth}
\centering
\begin{tabular}{|l|l|}
\hline
\multicolumn{2}{|p{2cm}|}{\centering\textbf{SWD}} \\ \hline
1               & 3V3               \\ \hline
2               & SWCLK             \\ \hline
3               & GND               \\ \hline
4               & SWDIO             \\ \hline
5               & NRST              \\ \hline
\end{tabular}
\hfill
\end{minipage}
\begin{minipage}[t][3cm][t]{0.24\textwidth}
\centering
\begin{tabular}{|l|l|}
\hline
\multicolumn{2}{|p{2cm}|}{\centering\textbf{UVLED}} \\ \hline
1               & LED ANODE                \\ \hline
2               & LED KATHODE                \\ \hline
\end{tabular}
\end{minipage}
\begin{minipage}[t][3.5cm][t]{0.24\textwidth}
\centering
\begin{tabular}{|l|l|}
\hline
\multicolumn{2}{|p{3cm}|}{\centering\textbf{MRS MODULE}} \\ \hline
1               & GND         \\ \hline
2               & VBAT        \\ \hline
3               & VBAT        \\ \hline
4               & GND         \\ \hline
5               & UART\verb|_|TX     \\ \hline
6               & UART\verb|_|RX     \\ \hline
7               & GND         \\ \hline
8               & 5V          \\ \hline
9               & 5V          \\ \hline
10              & GND         \\ \hline
\end{tabular}
\end{minipage}
\end{center}

\pagebreak
\section{MCU Firmware}

The firmware receives data using UART (115200 baud); the data are in the \verb|baca_protocol| format used by the \verb|mrs_serial| node.\\
The button on the PCB serves to "mute" the UVLEDs. This button toggles global enable flag in order to stop the blinking, but does not change any other settings and does not stop the counter. This flag can be set using the UART as well.\\
\\
All setting are stored in the internal FLASH memory and are retrieved on startup.\\
\\
The byte structure of the \verb|baca_protocol| can be seen in table \ref{tab:baca_protocol_table}.
The message starts with letter 'b' (0x62 in hex) and is followed by the length of the payload (1-255).
The payload then follows. The first byte of the payload is the \verb|Message ID| and the rest of the payload contains the data (if any). The last byte is the checksum which is a simple sum of all previous bytes.\\
\\
Several message types have been implemented to control the board.

\begin{table}[h]
\begin{tabular}{|c|c|c|c|c|c|}
\hline
\textbf{Byte}   & 0          & 1                     & 2 ... (n-1) & n        \\ \hline
\textbf{Value} & 'b' (0x62) & Length of the payload & Payload (Message ID and Data)       & Checksum \\ \hline
\end{tabular}
\caption{MRS MODULE - UVDAR: Baca Protocol Message}
\label{tab:baca_protocol_table}
\end{table}

\subsection{Message Types}
The available messages are described below:\\
\begin{itemize}
\item \textbf{Global Enable LEDs} - This is a software version of the HW switch on the PCB - This overrides, but saves all configuration and turns off all UVLEDs, or resumes the original settings.\\
\begin{flushleft}
\begin{tabular}{|l|}
\hline
Command Byte: 0x90													\\ \hline
Payload Size: 0														\\ \hline
\end{tabular}
\end{flushleft}

\item \textbf{Bulk Enable LEDs} - Enables or Disables the UVLED with the same index as the payload Byte. This will reset counters of all LEDs.\\
\begin{flushleft}
\begin{tabular}{|l|}
\hline
Command Byte: 0x91													\\ \hline
Payload size: 8 B													\\ \hline
Payload Bytes: 0x00 (UVLED Disabled), 0x01 (UVLED Enabled)			\\ \hline
Payload Byte 0: UVLED1 enabled =  0x00 (Disabled), 0x01 (Enabled)	\\ \hline
Payload Byte 1: UVLED2 enabled =  0x00 (Disabled), 0x01 (Enabled)	\\ \hline
Payload Byte 2: UVLED3 enabled =  0x00 (Disabled), 0x01 (Enabled)	\\ \hline
Payload Byte 3: UVLED4 enabled =  0x00 (Disabled), 0x01 (Enabled)	\\ \hline
Payload Byte 4: UVLED5 enabled =  0x00 (Disabled), 0x01 (Enabled)	\\ \hline
Payload Byte 5: UVLED6 enabled =  0x00 (Disabled), 0x01 (Enabled)	\\ \hline
Payload Byte 6: UVLED7 enabled =  0x00 (Disabled), 0x01 (Enabled)	\\ \hline
Payload Byte 7: UVLED8 enabled =  0x00 (Disabled), 0x01 (Enabled)	\\ \hline
\end{tabular}
\end{flushleft}

\item \textbf{Bulk Set Periods} - Sets blinking freqeuncy of the LED with the same index as the payload Byte. This will reset counters of all LEDs.\\
\begin{flushleft}
\begin{tabular}{|l|}
\hline
Command Byte: 0x92													\\ \hline
Payload size: 8 B													\\ \hline
Payload Byte 0: Desired frequency of the UVLED1						\\ \hline
Payload Byte 1: Desired frequency of the UVLED2						\\ \hline
Payload Byte 2: Desired frequency of the UVLED3						\\ \hline
Payload Byte 3: Desired frequency of the UVLED4						\\ \hline
Payload Byte 4: Desired frequency of the UVLED5						\\ \hline
Payload Byte 5: Desired frequency of the UVLED6						\\ \hline
Payload Byte 6: Desired frequency of the UVLED7						\\ \hline
Payload Byte 7: Desired frequency of the UVLED8						\\ \hline
\end{tabular}
\end{flushleft}

\item \textbf{Enable LED} - enables the UVLED with the specified index. This will reset the counter of the specified UVLED.\\
\begin{flushleft}
\begin{tabular}{|l|}
\hline
Command Byte: 0x93													\\ \hline
Payload Size: 2														\\ \hline
Payload Byte 0: UVLED index (0-7)									\\ \hline
Payload Byte 1: 0x00 (Disabled), 0x01 (Enabled)						\\ \hline
\end{tabular}
\end{flushleft}

\item \textbf{Set Period} - Sets blinking frequency of the UVLED with the specified index. This will reset the counter of the specified UVLED.\\
\begin{flushleft}
\begin{tabular}{|l|}
\hline
Command Byte: 0x94													\\ \hline
Payload Size: 2														\\ \hline
Payload Byte 0: LED index (0-7)										\\ \hline
Payload Byte 1: Desired frequency of the UVLED						\\ \hline
\end{tabular}
\end{flushleft}

\item \textbf{Get Enabled} - Returns 8 bytes. These bytes indicate if the UVLEDs are enabled or disabled.\\
\begin{flushleft}
\begin{tabular}{|l|}
\hline
Command Byte: 0x95															\\ \hline
Payload Size: 0																\\ \hline
Return Payload Size: 8														\\ \hline
Return Payload Byte 0: UVLED1 enabled =  0x00 (Disabled), 0x01 (Enabled)	\\ \hline
Return Payload Byte 1: UVLED2 enabled =  0x00 (Disabled), 0x01 (Enabled)	\\ \hline
Return Payload Byte 2: UVLED3 enabled =  0x00 (Disabled), 0x01 (Enabled)	\\ \hline
Return Payload Byte 3: UVLED4 enabled =  0x00 (Disabled), 0x01 (Enabled)	\\ \hline
Return Payload Byte 4: UVLED5 enabled =  0x00 (Disabled), 0x01 (Enabled)	\\ \hline
Return Payload Byte 5: UVLED6 enabled =  0x00 (Disabled), 0x01 (Enabled)	\\ \hline
Return Payload Byte 6: UVLED7 enabled =  0x00 (Disabled), 0x01 (Enabled)	\\ \hline
Return Payload Byte 7: UVLED8 enabled =  0x00 (Disabled), 0x01 (Enabled)	\\ \hline
\end{tabular}
\end{flushleft}

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

\begin{figure}[h]
\centering
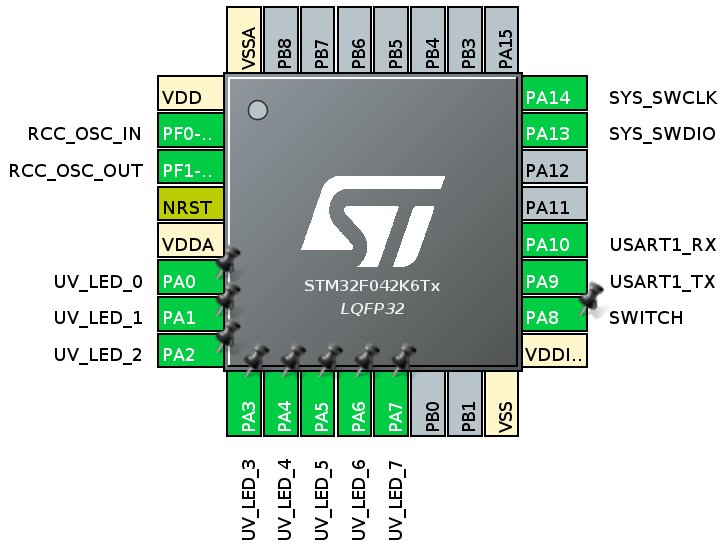
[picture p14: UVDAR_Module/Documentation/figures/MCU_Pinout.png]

\caption{MRS MODULE - UVDAR: MCU pinout}
\label{fig:mcu_pinout}
\end{figure}

The firmware is written with the need for versatility in mind and therefore is not optimal for specialised applications. The UVLED blinking is implemented using software PWM which allows us to change frequencies of individual channels, as is desired for research purposes. I suggest using hardware PWMs if the UVLEDs will have the same frequency. This is achievable only for UVLEDs 1 to 4 since these are connected to TIM2 channels 1 to 4. The other UVLED channels were moved to arbitrary pins for easier routing in the beginning and were left for legacy purposes. If hardware PWM for all channels is desired, then rearanging UVLEDs is necessary.

\pagebreak
\subsection{Software PWM for UVLEDs}
The UVLED blinking is implemented in \verb|uv_led_driver.c/h| files. To function properly the pins must be named as \verb|UV_LED_x| where \verb|x| is a number between 0 and 8. Of course, this can be changed by the programmer. These pins are used in the \verb|uv_led_init( void )| function to map them to an internally used array. This function also reads the frequency values and flags for enabling UVLEDs from the internal FLASH and resets the counters.\\
\\
The \verb|uv_led_set_frequency(uint8_t led_id, uint8_t frequency)| function sets the frequency of the selected UVLED. The input argument \verb|led_id| is index of the UVLED to be set starting from 0 and the \verb|frequency| is an integer value of desired frequency in range 1 to 60 Hz.\\
This function then calculates the number of ticks of the counter needed to toggle the LED (half of its total period). To calculate this value properly, the value of \verb|TIMER_FREQ| must be set to the frequency of the hardware timer used to increment the counter.\\
The calculated value is then saved to the internal FLASH.\\
\\
The \verb|uv_led_enable(uint8_t led_id, uint8_t enable)| function sets the enable flag of the selected UVLED. The input argument \verb|led_id| is index of the UVLED to be set starting from 0, with \verb|enable| as an integer of value 1 (true) or 0(false). Any other values are invalid.\\
The enable flag is then saved to the internal FLASH.\\
\\
The \verb|uv_led_toggle(uint8_t led_id)| function toggles the selected UVLED. The input argument \verb|led_id| is index of the UVLED to be set starting from 0.\\
This function is called if the counter value reaches the desired value. This is managed using the Timer Period Elapsed Callback Function \verb|HAL_TIM_PeriodElapsedCallback| where the counter is increased everytime the used timer's period elapses. The used timer in this appliation is \verb|TIM3| with a frequency of 10kHz.
\subsubsection{Global Enable Flag}
To be able to disable all UVLEDs on a button switch without affecting anything else, a simple flag was created. This flag toggles on with a button press (\verb|SWITCH|) or with receiving a global enable message using UART. This flag is used in the \verb|uv_led_toggle(uint8_t led_id)|.

\subsection{UART implementation}
The UART communication through USART1 is implemented using DMA with enabled IDLE interrupt for variable packet size. The message is then processed in \verb|USAR_UART_IDLECallback| where the data are passed to the \verb|process_uart_message()| function to check if the message has the correct format (if the checksum is correct and has one of the valid message IDs) and then calls the apropriate function.\\
The buffer is then cleared.

\pagebreak

\newgeometry{left=1cm,right=1cm}
\section{Bill Of Materials and Assembly Drawings}
\begin{longtable}{|p{5cm}|p{5cm}|p{5cm}|p{1.7cm}|}
\hline
\textbf{References} & \textbf{Value} & \textbf{Footprint} & \textbf{Quantity}\\ \hline
C1, C28,                                & 1uF                     & 0603                      & 2        \\ \hline
C2, C33, C5, C25,                       & 0.1uF                   & 0603                      & 4        \\ \hline
C4, C3, C22,                            & 10pF                    & 0603                      & 3        \\ \hline
C23,                                    & 1nF                     & 0603                      & 1        \\ \hline
C24,                                    & 10nF                    & 0603                      & 1        \\ \hline
C26,                                    & 100uF/10V               & 2312                      & 1        \\ \hline
C27, C21,                               & 22uF/25V                & 2412                      & 2        \\ \hline
C31, C32,                               & 10uF                    & 1206                      & 2        \\ \hline
D21,                                    & B340A                   & SMA                       & 1        \\ \hline
D31,                                    & 1N4148W-E3-08           & SOD-123                   & 1        \\ \hline
J1,                                     & Header\_1x10            & Header\_1x10\_P2.00mm     & 1        \\ \hline
J11, J12, J13, J15, J16, J17, J18, J14, & JST-PH\_2               & JST\_PH\_2                & 8        \\ \hline
L21,                                    & SRP6540-8R2M            & SRP6540                   & 1        \\ \hline
LD1,                                    & GREEN                   & 0603                      & 1        \\ \hline
R1, R22,                                & 10k                     & 0603                      & 2        \\ \hline
R2, R23,                                & 1k                      & 0603                      & 2        \\ \hline
R11, R12, R13, R14, R15, R16, R17, R18, & 3R3-0.5\%               & 0603                      & 8        \\ \hline
R21,                                    & 27k4                    & 0603                      & 1        \\ \hline
SW1,                                    & Push-Switch\_SMT\_6x6mm & Tactile\_Switch\_6x6\_SMT & 1        \\ \hline
SWD1,                                   & SWO                     & Header\_1x05\_P2.54mm     & 1        \\ \hline
U1,                                     & STM32F042K6T6           & LQFP-32\_7x7mm\_P0.8mm    & 1        \\ \hline
U2,                                     & TPS54331DR              & SOIC-8                    & 1        \\ \hline
U3,                                     & MCP1825S-3302E          & SOT-223-3(TAB-pin-2)      & 1        \\ \hline
U11, U12, U13, U14, U15, U16, U17, U18, & BCR421UW6               & SOT-26-6                  & 8        \\ \hline
Y1,                                     & 16 MHz                  & ABM8G          & 1        \\ \hline

\caption{MRS MODULE - UVDAR: Bill Of Materials}
\label{tab:bom}
\end{longtable}
\vfill
\restoregeometry

\pagebreak
% change scale and angle accordingly
\includepdf[pages=-, scale=0.8, angle=270, pagecommand={}]{figures/Assembly_top.pdf}

\pagebreak
\includepdf[pages=-, scale=0.8, angle=270, pagecommand={}]{figures/Assembly_bot.pdf}

\pagebreak
\section{Schematic}
\begin{center}

\end{center}
\pagebreak
\includepdf[pages=-,scale=0.85, angle=270,pagecommand={}]{figures/Schematic.pdf}

\end{document}

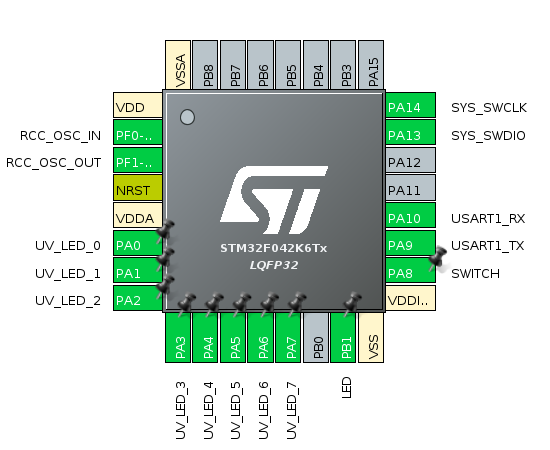
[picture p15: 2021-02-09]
UVDAR_Module/PCB/MCU_Pinout.png

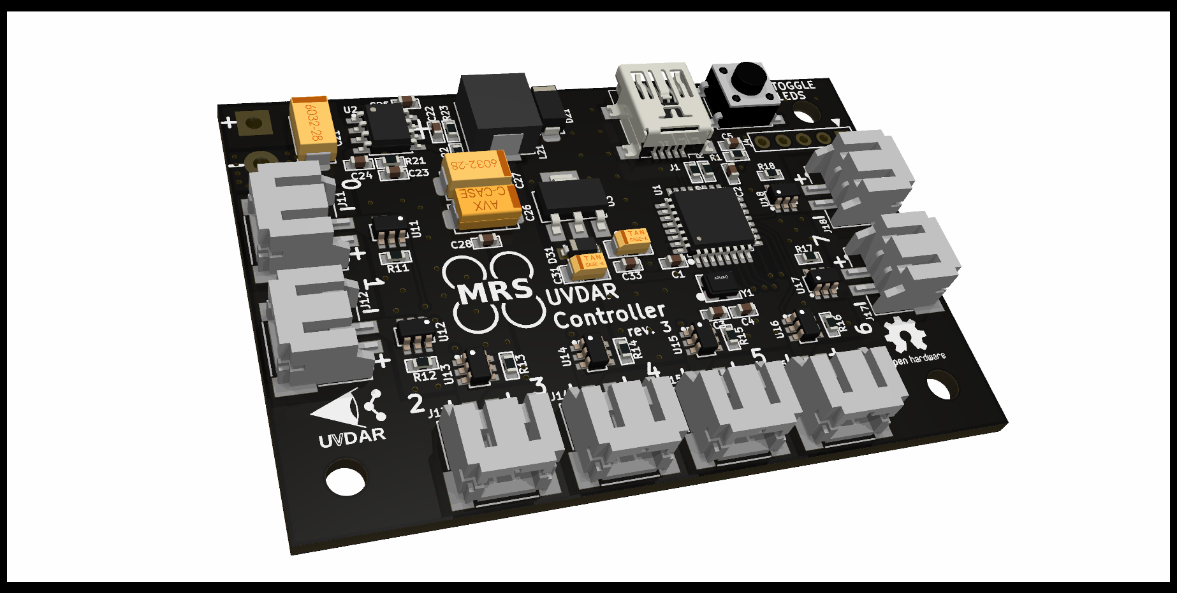
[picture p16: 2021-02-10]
UVDAR_Standalone/PCB/UVDAR_Board.png

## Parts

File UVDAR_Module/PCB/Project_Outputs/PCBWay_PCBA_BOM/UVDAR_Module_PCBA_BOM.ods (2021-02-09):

Item # | Reference | Quantity | Value | Manufacturer | Code | Description | Footprint | Mouser | Farnell | TME | Digikey
1 | C1, | 1 | 1uF/25V | Würth Elektronik | 885012106022 | X5R Ceramic Capacitor; X5R Ceramic Capacitor | 0603 | 710-885012106022 | 2495150 | CL10A105KP8NNNC | 732-7919-1-ND
2 | C2, C33, C5, C22, C24, C25, C27, | 7 | 0.1uF/50V | Samsung Electro-Mechanics | CL10B104KB8NNNC | X7R Ceramic Capacitor; 0.1uF/50V | 0603 | 187-CL10B104KB8NNNC | 1301804 | CL10B104KB8NNNC | 1276-1000-1-ND
3 | C4, C3, | 2 | 10pF/50V | Würth Elektronik | 885012005055 | C0G (NP0) Ceramic Capacitor; 10pF/50V | 0603 | 710-885012005055 | 2533813 | VJ0402A100JXAPW1BC | 732-7469-1-ND
4 | C23, | 1 | 2.2uF/35V | Murata Electronics | GRM188R6YA225MA12D | X5R Ceramic Capacitor; 2.2uF/35V | 0603 | 81-GRM188R6YA225MA2D | 2611926 | CL10A225KA8NNNC | 490-10486-1-ND
5 | C26, | 1 | 47uF/10V | Taiyo Yuden | LMK316ABJ476ML-T | X5R Ceramic Capacitor; 47uF/10V | 1206 | 963-LMK316ABJ476ML-T | 2426965 | CL31A476MPHNNNE | 587-3428-1-ND
6 | C31, C32, C21, | 3 | 10uF/35V | Samsung Electro-Mechanics | CL31A106MBHNNNE | X5R Ceramic Capacitor; 10uF/35V | 1206 | 187-CL31A106MBHNNNE | 2672214 | CL31A106KBHNNNE | 1276-6736-1-ND
7 | D31, | 1 | 1N4148W-E3-08 | Vishay Semiconductor Diodes Division | 1N4148W-E3-08 | DIODE GEN PURP 75V 150MA SOD123 | SOD-123 | 78-1N4148W-E3-08 | 2433353 | 1N4148W-E3-08 | 1N4148W-E3-08CT-ND
8 | J11, J12, J13, J15, J16, J17, J18, J14, | 8 | JST-PH_2 | JST | S2B-PH-SM4-TB(LF)(SN) | CONN HEADER SMD R/A 2POS 2MM | JST_PH_2 | X | 9492615 | S2B-PH-SM4-TB | 455-1749-1-ND
9 | L21, | 1 | 2.2uH | Abracon LLC | ASPI-0418FS-2R2M-T3 | FIXED IND 2.2UH 2.9A 37 MOHM SMD | ASPI-0418 | 815-ASPI418FS2R2MT3 | 2408938 | DJNR4018-2R2-S | 535-10759-1-ND
10 | LD1, | 1 | ORANGE | Würth Elektronik | 150060AS75000 | WL-SMCW SMT MONO-COLOR CHIP LED | 0603 | 710-150060AS75000 | 2900757 | LL-S192PUAC-2A | 732-150060AS75000CT-ND
11 | R1, | 1 | 10k | TE Connectivity Passive Product | CRGCQ0603J10K | RES 0603 10K 5% | 0603 | 279-CRGCQ0603J10K | 2861870 | CRCW060310K0JNTABC | A130097CT-ND
12 | R2, | 1 | 1k | TE Connectivity Passive Product | CRGCQ0603J1K0 | RES 0603 1K0 5% | 0603 | 279-CRGCQ0603J1K0 | 2861864 | WF06P-1K-5% | A130091CT-ND
13 | R11, R12, R13, R14, R15, R16, R17, R18, | 8 | 3R3-0.5% | Vishay Dale | CRCW06033R30FKEA | RES SMD 3.3 OHM 1% 1/10W 0603 | 0603 | 71-CRCW06033R30FKEA | 2447365 | ARG0603-3R3-0.5% | 541-3.30HHCT-ND
14 | R22, | 1 | 88k7 | Stackpole Electronics Inc | RMCF0603FT88K7 | RES 88.7K OHM 1% 1/10W 0603 | 0603 | 652-CR0603FX-8872ELF | 2670914 | SMD0603-88.7K-1% | 738-RMCF0603FT88K7CT-ND
15 | R23, | 1 | 22k1 | Yageo | RC0603FR-0722K1L | RES SMD 22.1K OHM 1% 1/10W 0603 | 0603 | 603-RC0603FR-0722K1L | 2694776 | SMD0603-22K1-1% | 311-22.1KHRCT-ND
16 | SW1, | 1 | Push-Switch_SMT_6x6mm | C&K | PTS645SM43SMTR92 LFS | SWITCH TACTILE SPST-NO 0.05A 12V | Tactile_Switch_6x6_SMT | 611-PTS645SM43SMTR92 | 2320087 | PTS645SM43SMTR92LF | CKN9112CT-ND
17 | U1, | 1 | STM32F042K6T6 | STMicroelectronics | STM32F042K6T6 | IC MCU 32BIT 32KB FLASH 32LQFP | LQFP-32_7x7mm_P0.8mm | 511-STM32F042K6T6 | 2750629 | STM32F042K6T6 | 497-14647-ND
18 | U2, | 1 | LMR23625CFPDRRR | Texas Instruments | LMR23625CFPDRRT | IC REG BUCK ADJ 2.5A 12SON | WSON12_3x3mm | 595-LMR23625CFPDRRT |  |  | 296-48825-1-ND
19 | U3, | 1 | MCP1703A-3302E/DB | Microchip Technology | MCP1703A-3302E/DB | IC REG LIN 3.3V 250MA SOT223-3 | SOT-223-3(TAB-pin-2) | 579-MCP1703AT3302EDB | 2113888 | MCP1703A-3302E/DB | MCP1703A-3302E/DB-ND
20 | U11, U12, U13, U14, U15, U16, U17, U18, | 8 | BCR421UW6 | Diodes Incorporated | BCR421UW6-7 | IC LED DRIVER SOT26 | SOT-26-6 | 621-BCR421UW6-7 | 3127238 | BCR421UW6-7 | BCR421UW6-7DICT-ND
21 | Y1, | 1 | ABM8G | Abracon LLC | ABM8G-16.000MHZ-4Y-T3 | CRYSTAL 16.0000MHZ 10PF SMD | ABM8G | 815-ABM8G-16-4YT3 | 2467842 | ABM8-16.000MHZ-B2 | 535-10907-1-ND

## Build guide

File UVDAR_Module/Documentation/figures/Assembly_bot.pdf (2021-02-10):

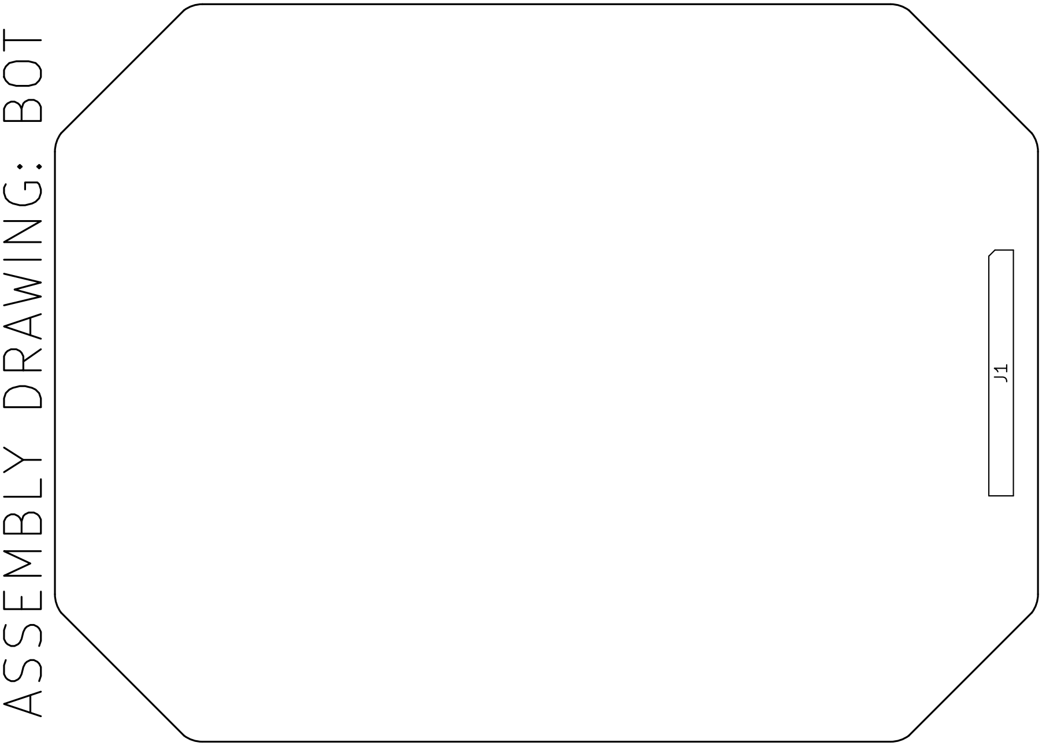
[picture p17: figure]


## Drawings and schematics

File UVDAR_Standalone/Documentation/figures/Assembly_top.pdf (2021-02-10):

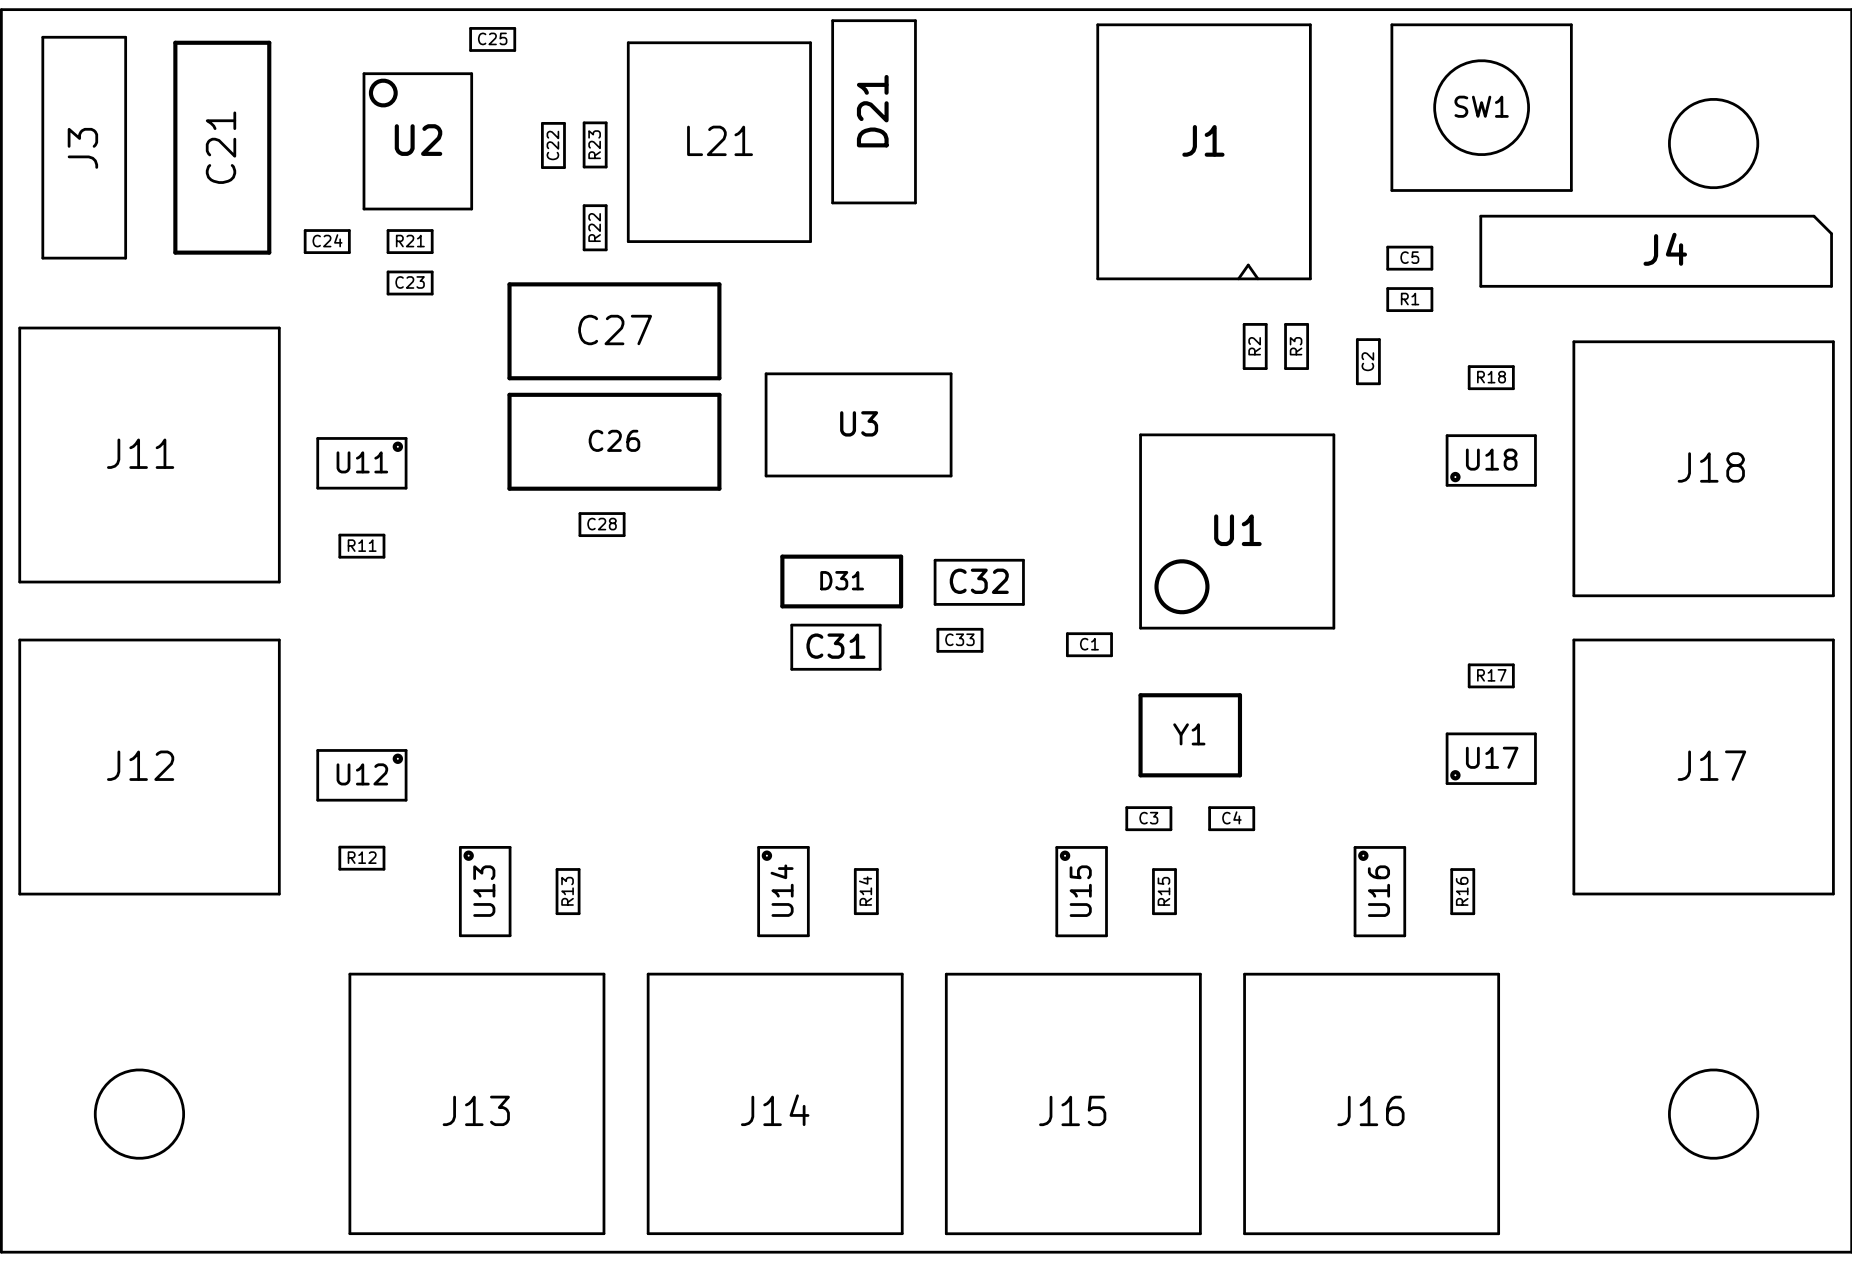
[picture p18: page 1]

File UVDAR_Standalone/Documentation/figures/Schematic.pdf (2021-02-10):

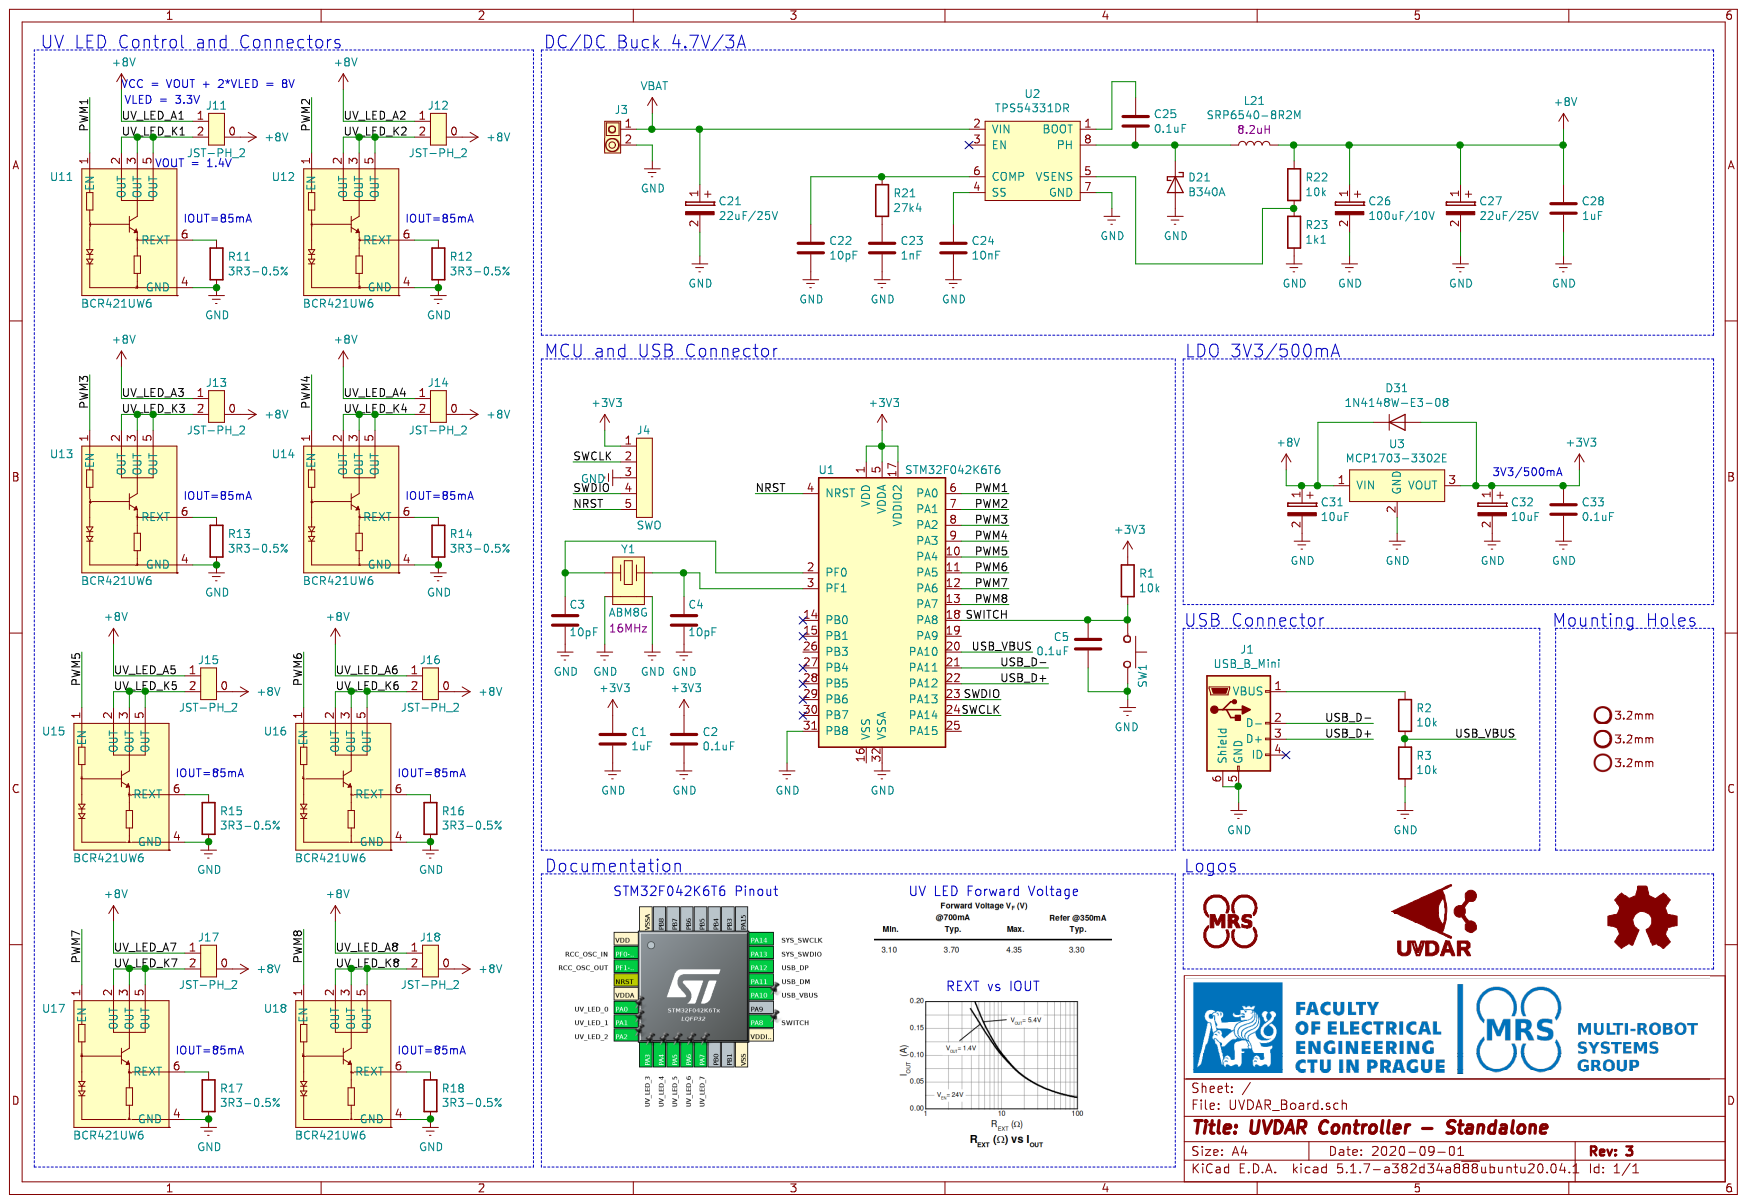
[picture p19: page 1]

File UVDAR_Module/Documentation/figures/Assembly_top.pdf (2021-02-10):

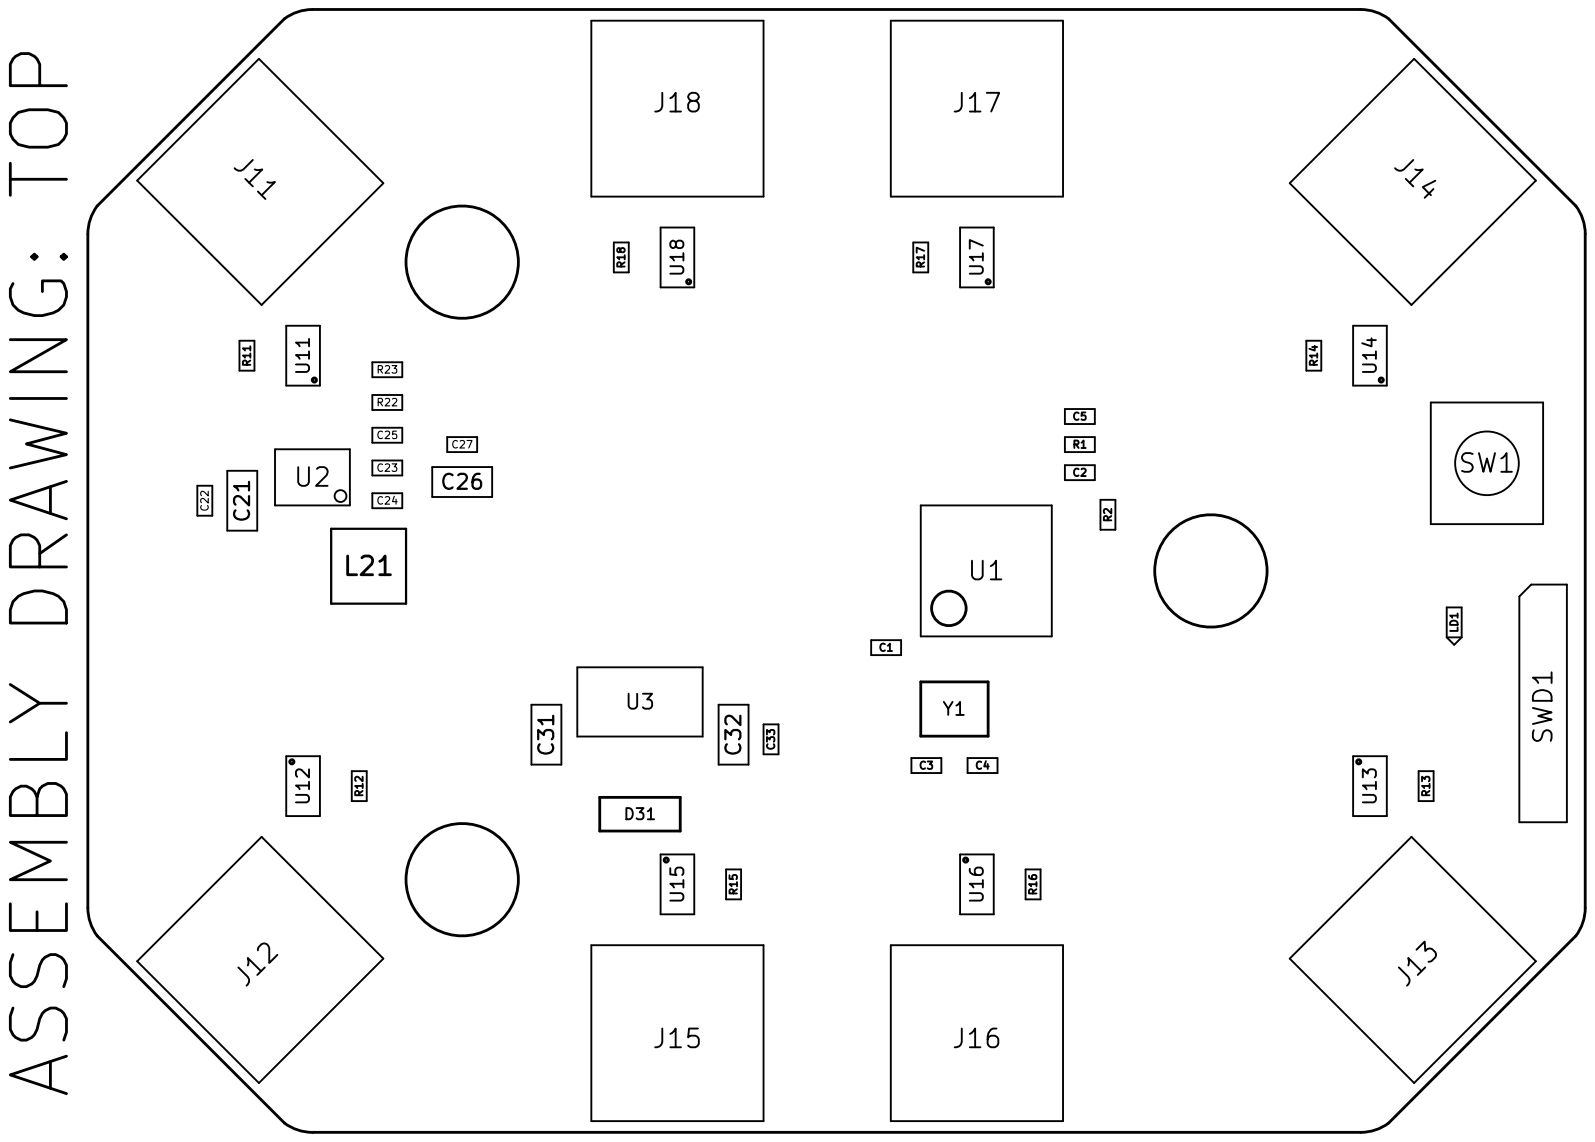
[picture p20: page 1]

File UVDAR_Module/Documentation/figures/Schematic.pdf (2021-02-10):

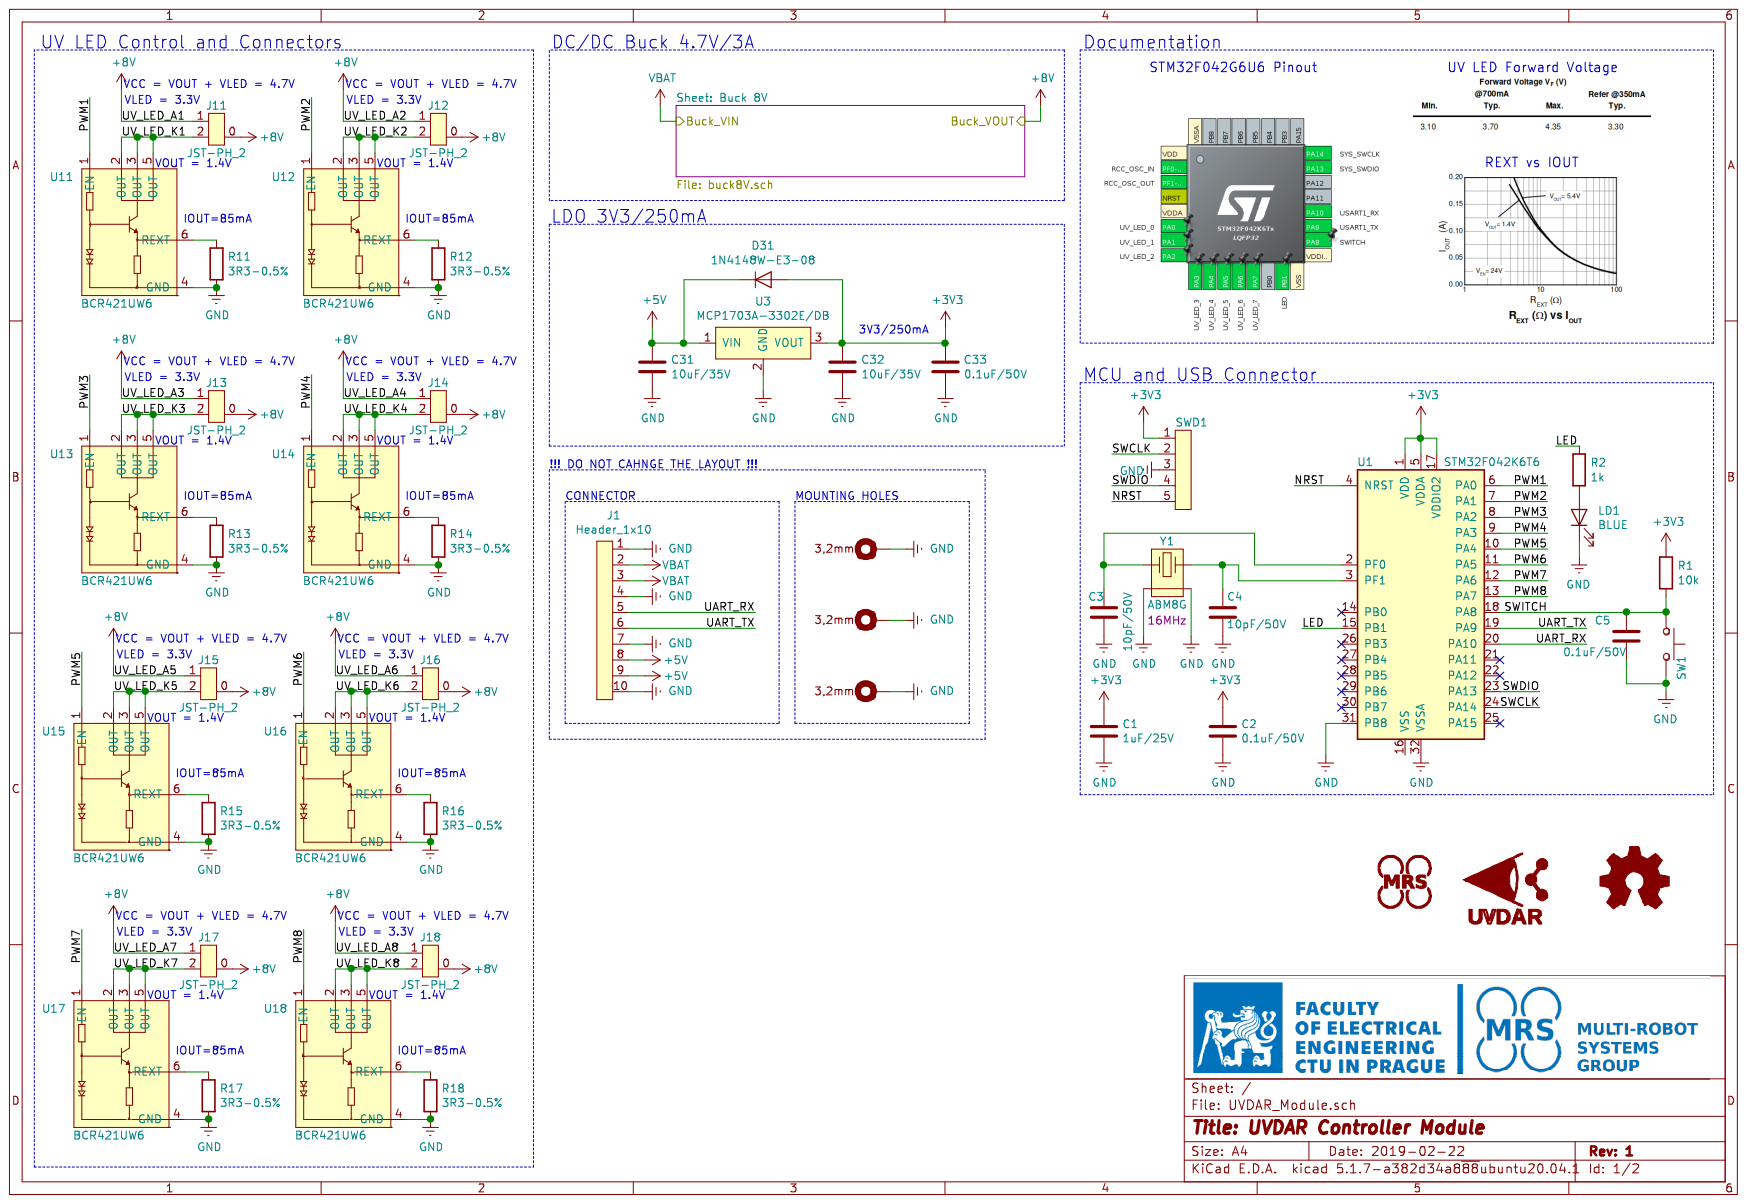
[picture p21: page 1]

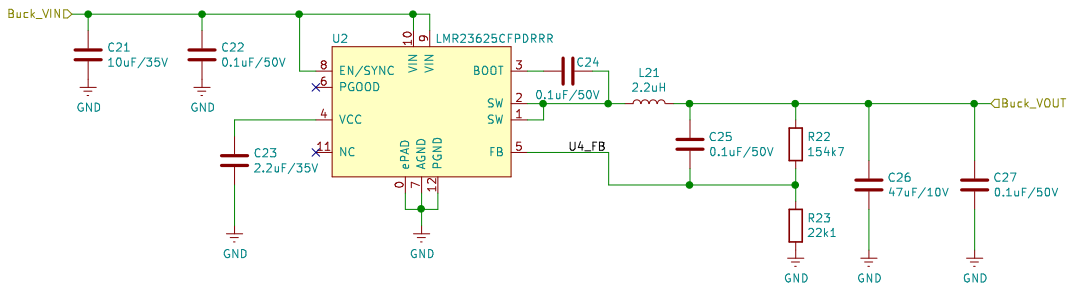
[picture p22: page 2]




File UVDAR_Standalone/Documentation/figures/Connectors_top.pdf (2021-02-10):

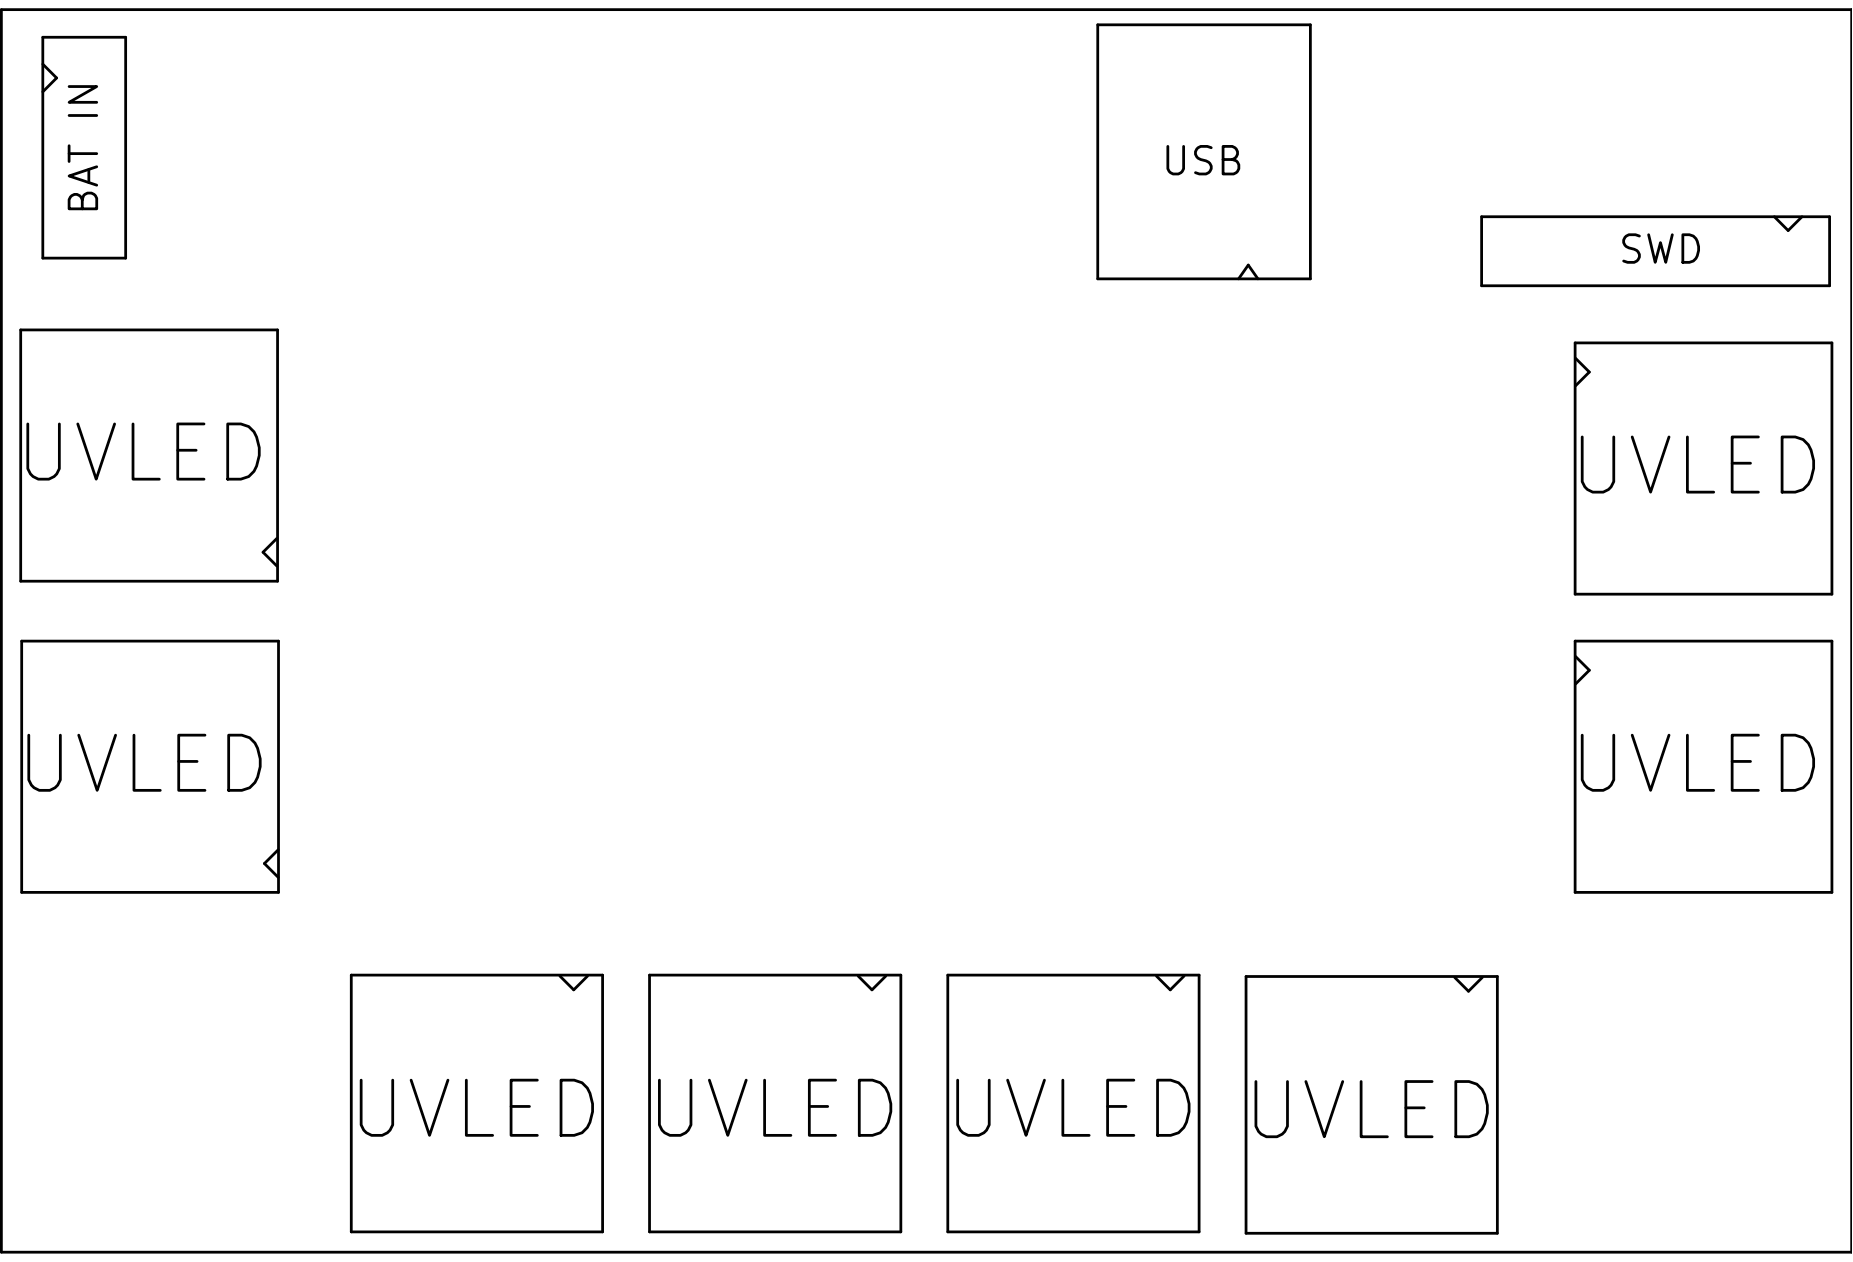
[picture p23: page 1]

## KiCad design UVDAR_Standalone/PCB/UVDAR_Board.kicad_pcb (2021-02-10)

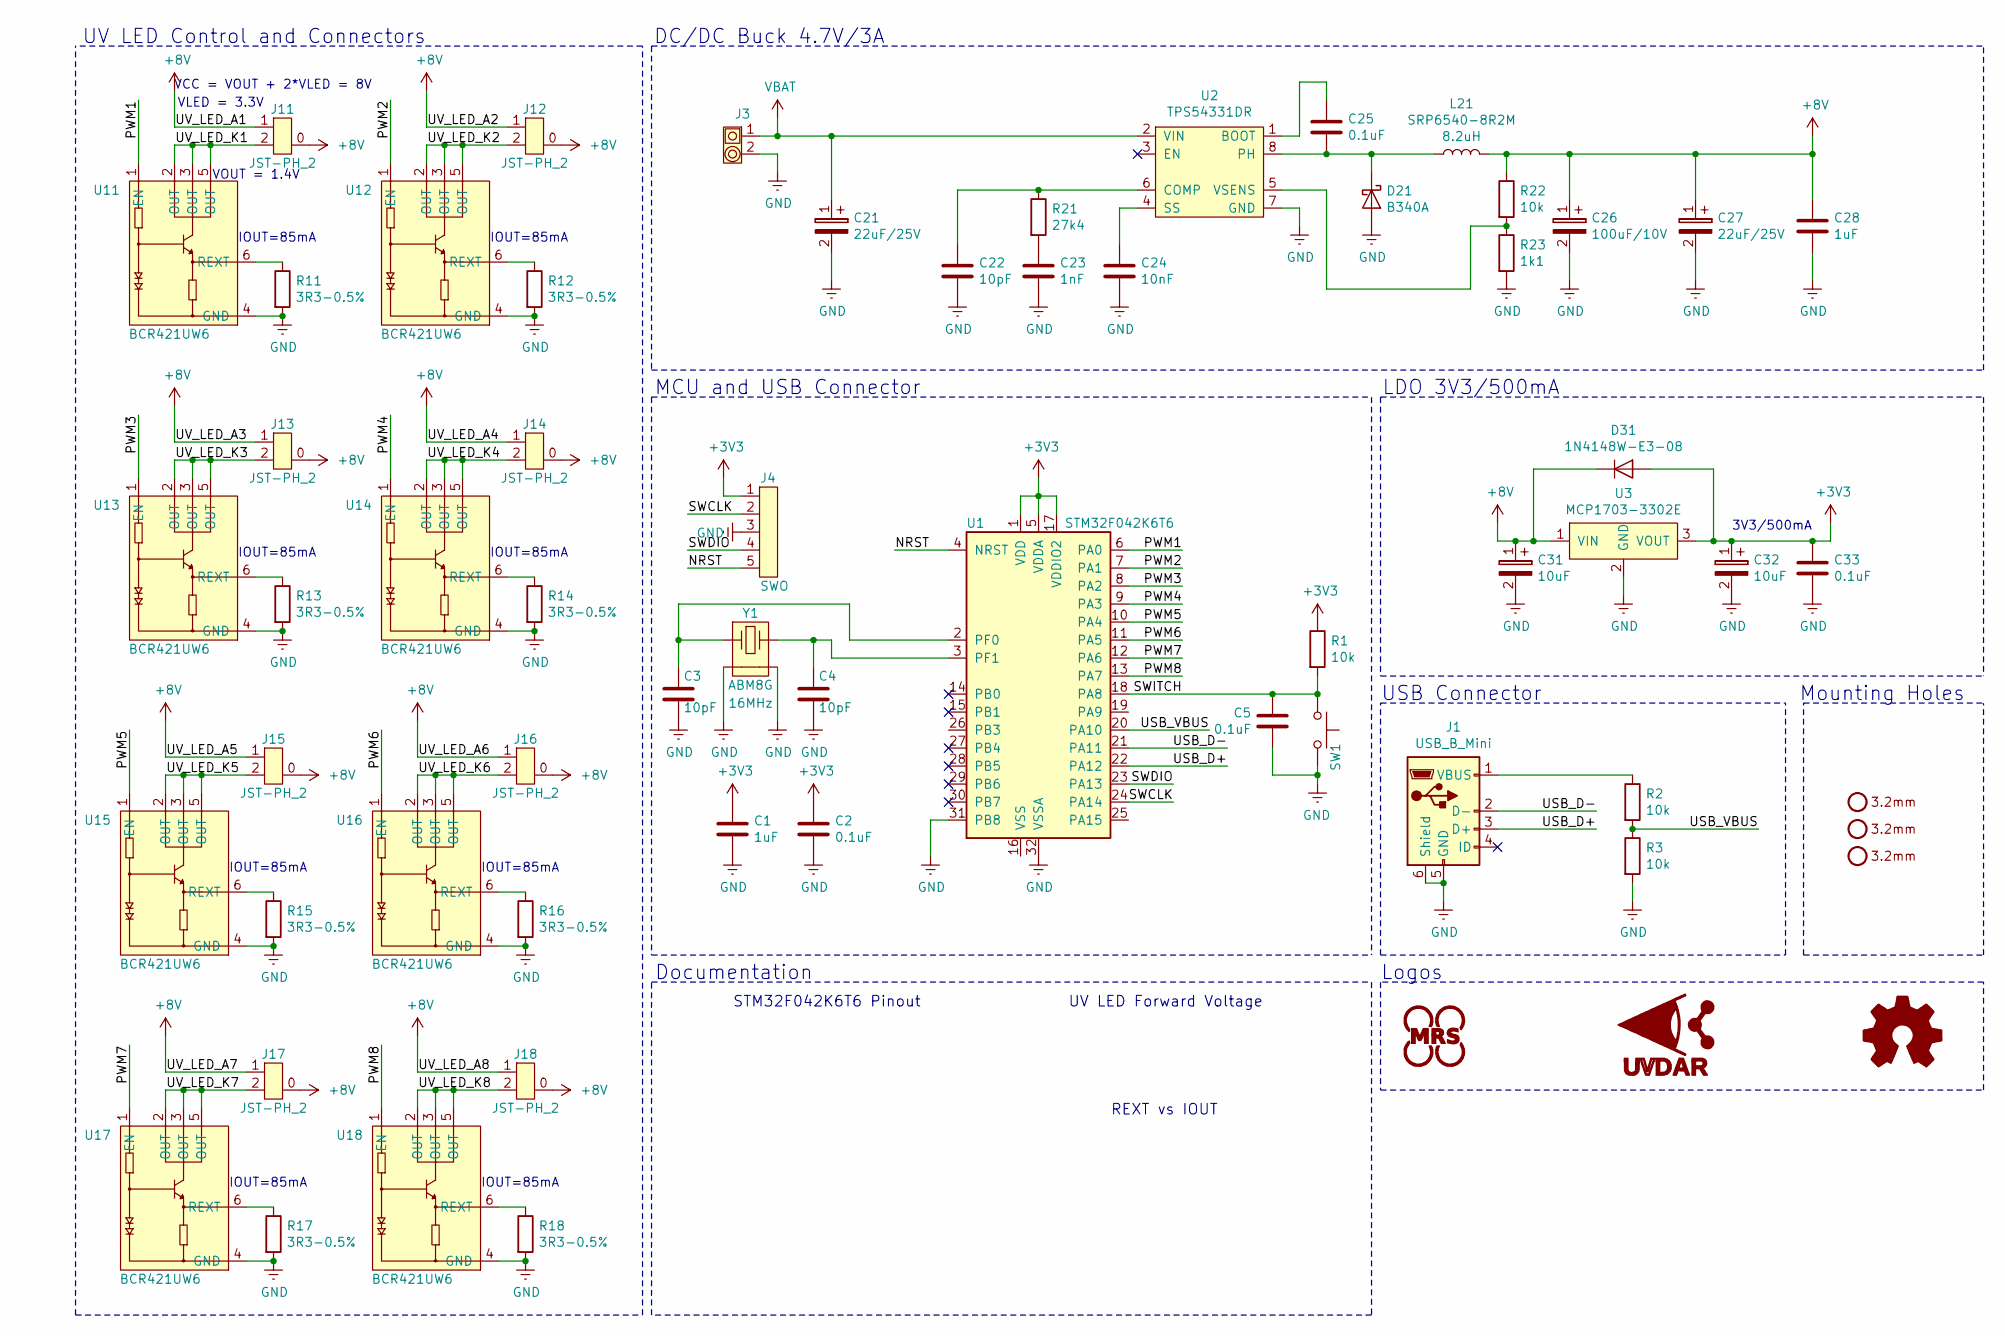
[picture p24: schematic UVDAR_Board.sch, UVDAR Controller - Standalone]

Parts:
C1, C28: 1uF; C0603; Farnell 2533943
C2, C5, C25, C33: 0.1uF; C0603; Farnell 2821272
C3, C4, C22: 10pF; C0603; Mouser 710-885012006051
C21, C27: 22uF/25V; CTAN2412; Farnell 2353066
C23: 1nF; C0603; Farnell 2534019
C24: 10nF; C0603; Farnell 1759102
C26: 100uF/10V; CTAN2312; Farnell 197180
C31, C32: 10uF; CTAN1206; Farnell 197130
D21: B340A; D_SMA; Farnell 2335183
D31: 1N4148W-E3-08; SOD-123; Farnell 2433353
H1, H2, H3: Mounting_hole_unplated_3,2mm
J1: USB_B_Mini; USB_Mini-B_Lumberg_2486_01_Horizontal; Farnell 1243250
J3: Power_Input; power_connector_small
J4: SWO; Header_1x05_P2.54mm
J11, J12, J13, J14, J15, J16, J17, J18: JST-PH_2; JST_PH_2; Mouser X
L21: SRP6540-8R2M; L_SRP6540; Farnell 2309903
LOGO1: MRS_Logo; MRS_10mm
LOGO2: UVDAR_Logo; UVDAR_7mm
LOGO3: Logo_Open_Hardware_Small; OSHW-Logo2_7.3x6mm_SilkScreen
R1, R2, R3, R22: 10k; R0603; Mouser 71-CRCW0603-10K-E3
R11, R12, R13, R14, R15, R16, R17, R18: 3R3-0.5%; R0603; Farnell 2447365
R21: 27k4; R0603; Mouser 652-CR0603FX-2742ELF
R23: 1k1; R0603; Mouser *
SW1: Push-Switch_SMT_6x6mm; Tactile_Switch_6x6_SMT; Farnell 2320087
U1: STM32F042K6T6; LQFP-32_7x7mm_P0.8mm; Farnell 2750629
U2: TPS54331DR; SOIC-8; Farnell 2781730
U3: MCP1703-3302E; SOT-223-3(TAB-pin-2); Farnell *
U11, U12, U13, U14, U15, U16, U17, U18: BCR421UW6; SOT-26-6; Mouser 621-BCR421UW6-7
Y1: ABM8G; Farnell 2467841

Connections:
+3V3: C1.1, C2.1, C32.1, C33.1, D31.2 (A), J4.1, R1.1, U1.1 (VDD), U1.5 (VDDA), U1.17 (VDDIO2), U3.3 (VOUT)
+8V: C26.1, C27.1, C28.1, C31.1, D31.1 (K), J11.0, J11.1, J12.0, J12.1, J13.0, J13.1, J14.0, J14.1, J15.0, J15.1, J16.0, J16.1, J17.0, J17.1, J18.0, J18.1, L21.2, R22.1, U3.1 (VIN)
/NRST: J4.5, U1.4 (NRST)
/PWM1: U1.6 (PA0), U11.1 (EN)
/PWM2: U1.7 (PA1), U12.1 (EN)
/PWM3: U1.8 (PA2), U13.1 (EN)
/PWM4: U1.9 (PA3), U14.1 (EN)
/PWM5: U1.10 (PA4), U15.1 (EN)
/PWM6: U1.11 (PA5), U16.1 (EN)
/PWM7: U1.12 (PA6), U17.1 (EN)
/PWM8: U1.13 (PA7), U18.1 (EN)
/SWCLK: J4.2, U1.24 (PA14)
/SWDIO: J4.4, U1.23 (PA13)
/SWITCH: C5.1, R1.2, SW1.2, U1.18 (PA8)
/USB_D+: J1.3 (D+), U1.22 (PA12)
/USB_D-: J1.2 (D-), U1.21 (PA11)
/USB_VBUS: R2.2, R3.1, U1.20 (PA10)
/UV_LED_K1: J11.2, U11.2 (OUT), U11.3 (OUT), U11.5 (OUT)
/UV_LED_K2: J12.2, U12.2 (OUT), U12.3 (OUT), U12.5 (OUT)
/UV_LED_K3: J13.2, U13.2 (OUT), U13.3 (OUT), U13.5 (OUT)
/UV_LED_K4: J14.2, U14.2 (OUT), U14.3 (OUT), U14.5 (OUT)
/UV_LED_K5: J15.2, U15.2 (OUT), U15.3 (OUT), U15.5 (OUT)
/UV_LED_K6: J16.2, U16.2 (OUT), U16.3 (OUT), U16.5 (OUT)
/UV_LED_K7: J17.2, U17.2 (OUT), U17.3 (OUT), U17.5 (OUT)
/UV_LED_K8: J18.2, U18.2 (OUT), U18.3 (OUT), U18.5 (OUT)
GND: C1.2, C2.2, C3.2, C4.2, C5.2, C21.2, C22.2, C23.2, C24.2, C26.2, C27.2, C28.2, C31.2, C32.2, C33.2, D21.2 (A), J1.5 (GND), J1.6 (Shield), J3.2, J4.3, R3.2, R11.2, R12.2, R13.2, R14.2, R15.2, R16.2, R17.2, R18.2, R23.2, SW1.1, U1.31 (PB8), U1.32 (VSSA), U2.7 (GND), U3.2 (GND), U11.4 (GND), U12.4 (GND), U13.4 (GND), U14.4 (GND), U15.4 (GND), U16.4 (GND), U17.4 (GND), U18.4 (GND), Y1.2, Y1.4
unnamed: C3.1, U1.2 (PF0), Y1.1
unnamed: C4.1, U1.3 (PF1), Y1.3
unnamed: C22.1, R21.1, U2.6 (COMP)
unnamed: C23.1, R21.2
unnamed: C24.1, U2.4 (SS)
unnamed: C25.1, U2.1 (BOOT)
unnamed: C25.2, D21.1 (K), L21.1, U2.8 (PH)
unnamed: J1.1 (VBUS), R2.1
unnamed: R11.1, U11.6 (REXT)
unnamed: R12.1, U12.6 (REXT)
unnamed: R13.1, U13.6 (REXT)
unnamed: R14.1, U14.6 (REXT)
unnamed: R15.1, U15.6 (REXT)
unnamed: R16.1, U16.6 (REXT)
unnamed: R17.1, U17.6 (REXT)
unnamed: R18.1, U18.6 (REXT)
unnamed: R22.2, R23.1, U2.5 (VSENS)
VBAT: C21.1, J3.1, U2.2 (VIN)

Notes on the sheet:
VOUT = 1.4V
VCC = VOUT + 2*VLED = 8V
VLED = 3.3V
UV LED Forward Voltage
STM32F042K6T6 Pinout
REXT vs IOUT
IOUT=85mA
UV LED Control and Connectors
Documentation
MCU and USB Connector
3V3/500mA
LDO 3V3/500mA
DC/DC Buck 4.7V/3A
USB Connector
Mounting Holes
Logos

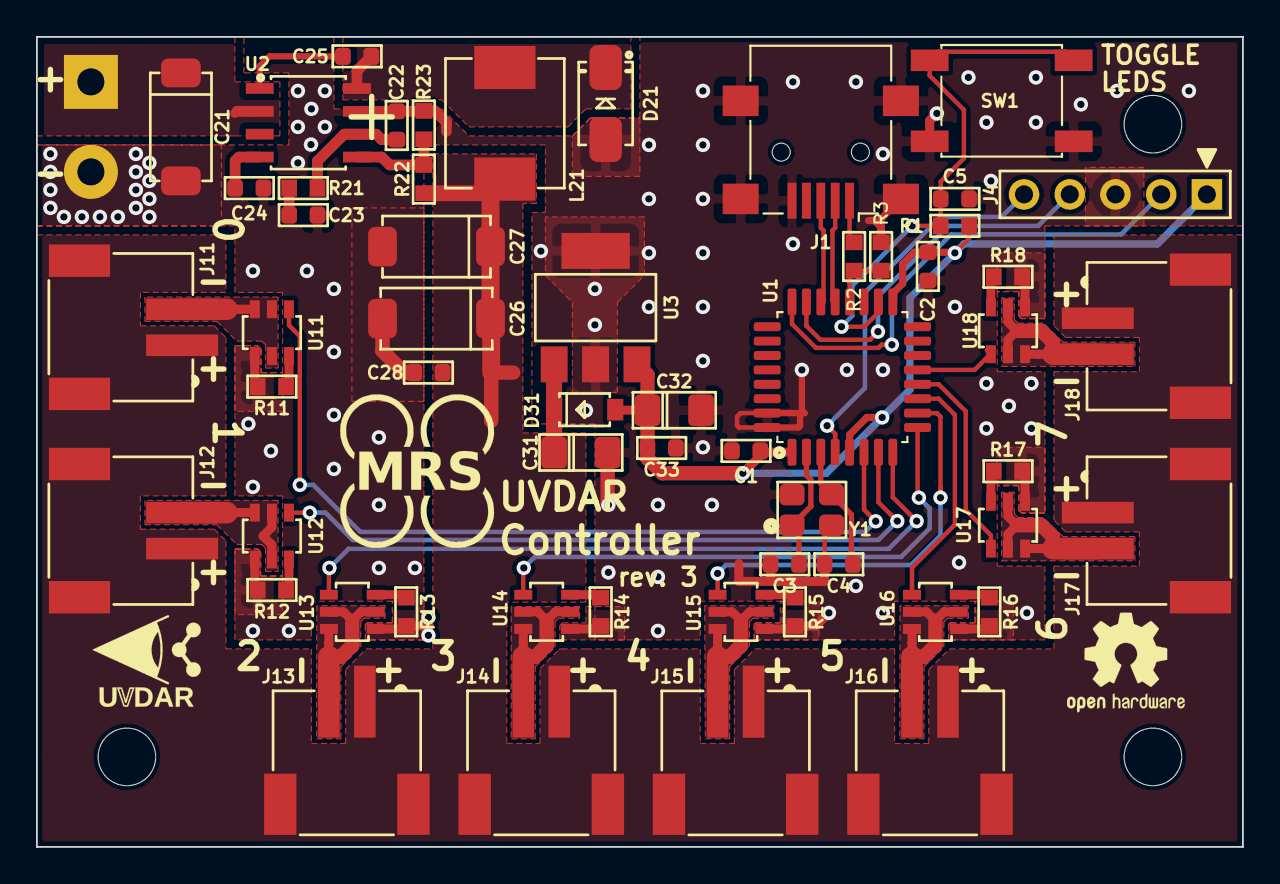
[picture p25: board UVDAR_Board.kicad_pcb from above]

Board: 2 copper layers, 67.0 x 45.0 mm, 63 parts (0 on the bottom side), 44 nets.

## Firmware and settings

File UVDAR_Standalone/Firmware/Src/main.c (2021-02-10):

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
/* Includes ------------------------------------------------------------------*/
#include "main.h"
#include "usb_device.h"

/* USER CODE BEGIN Includes */
#include "uv_led_driver.h"
#include "stm32f0xx_hal_flash_ex.h"
/* USER CODE END Includes */

/* USER CODE BEGIN PD */
#define FW_VERSION_H	1
#define FW_VERSION_L	0

#define BUFFER_SIZE 255
/* USER CODE END PD */

TIM_HandleTypeDef htim3;

/* USER CODE BEGIN PV */
/*osThreadId usb_read_taskHandle;
osThreadId usb_write_taskHandle;

osSemaphoreId semaphore_usbHandle;*/

//extern uint8_t usb_rx_buffer [64];
//extern uint32_t usb_rx_buffer_length;
//extern uint8_t new_data_received;
//extern uint8_t UserRxBufferFS[64];

extern uint32_t uv_led_counter[8];
extern uint32_t uv_led_periods_ms[8];
extern uint8_t enable_global;

uint8_t usb_rx_buff[BUFFER_SIZE];
uint8_t usb_rx_buff_size = 0;

/* USER CODE END PV */

void SystemClock_Config(void);
static void MX_GPIO_Init(void);
static void MX_TIM3_Init(void);
/**
  * @brief  The application entry point.
  * @retval int
  */
int main(void)
{
  /* MCU Configuration--------------------------------------------------------*/

  /* Reset of all peripherals, Initializes the Flash interface and the Systick. */
  HAL_Init();

  /* Configure the system clock */
  SystemClock_Config();

  /* Initialize all configured peripherals */
  MX_GPIO_Init();
  MX_USB_DEVICE_Init();
  MX_TIM3_Init();
  /* USER CODE BEGIN 2 */

  // Initialize UV LEDs - sets pins and loads values from FLASH
  uv_led_init();

  // Start TIM3
  HAL_TIM_Base_Start_IT(&htim3);

  /* USER CODE END 2 */

  /* Infinite loop */
  /* USER CODE BEGIN WHILE */
  while (1)
  {
    /* USER CODE END WHILE */

    /* USER CODE BEGIN 3 */
  }
  /* USER CODE END 3 */
}

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
/* USER CODE BEGIN 4 */

void HAL_GPIO_EXTI_Callback(uint16_t GPIO_Pin)
{
	// If the Interrupt came from SWITCH Pin
	if (GPIO_Pin == SWITCH_Pin)
	{
		// Toggle the UVLEDs global enable flag
		enable_global = !enable_global;
	}
}

/**
 * @brief  Period elapsed callback in non blocking mode
 * @note   This function is called  when TIM1 interrupt took place, inside
 * HAL_TIM_IRQHandler(). It makes a direct call to HAL_IncTick() to increment
 * a global variable "uwTick" used as application time base.
 * @param  htim : TIM handle
 * @retval None
 */
void HAL_TIM_PeriodElapsedCallback(TIM_HandleTypeDef *htim)
{
 /* USER CODE BEGIN Callback 0 */
	// Check if the callback came from TIM3
	if (htim->Instance == TIM3)
	{
		// Check UVLED toggle counters
		for (int i = 0; i < 8; i++)
		{
			// If toggle counter reached the max value toggle the UVLED and reset counter
			if (uv_led_counter[i] >= uv_led_periods_ms[i])
			{
				uv_led_toggle(i);
				uv_led_counter[i] = 0;
			// increment counter
			} else{
				uv_led_counter[i]++;
			}
		}
	}
 /* USER CODE END Callback 0 */
 if (htim->Instance == TIM3) {
   HAL_IncTick();
 }
}
/* USER CODE END 4 */
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


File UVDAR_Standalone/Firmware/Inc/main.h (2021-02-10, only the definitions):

#define UV_LED_0_Pin GPIO_PIN_0
#define UV_LED_0_GPIO_Port GPIOA
#define UV_LED_1_Pin GPIO_PIN_1
#define UV_LED_1_GPIO_Port GPIOA
#define UV_LED_2_Pin GPIO_PIN_2
#define UV_LED_2_GPIO_Port GPIOA
#define UV_LED_3_Pin GPIO_PIN_3
#define UV_LED_3_GPIO_Port GPIOA
#define UV_LED_4_Pin GPIO_PIN_4
#define UV_LED_4_GPIO_Port GPIOA
#define UV_LED_5_Pin GPIO_PIN_5
#define UV_LED_5_GPIO_Port GPIOA
#define UV_LED_6_Pin GPIO_PIN_6
#define UV_LED_6_GPIO_Port GPIOA
#define UV_LED_7_Pin GPIO_PIN_7
#define UV_LED_7_GPIO_Port GPIOA
#define SWITCH_Pin GPIO_PIN_8
#define SWITCH_GPIO_Port GPIOA
#define SWITCH_EXTI_IRQn EXTI4_15_IRQn
#define USB_VBUS_Pin GPIO_PIN_10
#define USB_VBUS_GPIO_Port GPIOA
#define USB_VBUS_EXTI_IRQn EXTI4_15_IRQn
#define ADDR_FLASH_PAGE_0      ((uint32_t)0x08000000) /* Base @ of Page 0, 1 Kbyte */
#define FLASH_USER_START_ADDR   ADDR_FLASH_PAGE_28   /* Start @ of user Flash area */
#define FLASH_USER_END_ADDR     ADDR_FLASH_PAGE_30 + FLASH_PAGE_SIZE   /* End @ of user Flash area */
#define FLASH_UVLEDS_ENABLED_ADDR 		ADDR_FLASH_PAGE_28
#define FLASH_UVLEDS_PERIODS_ADDR			ADDR_FLASH_PAGE_29

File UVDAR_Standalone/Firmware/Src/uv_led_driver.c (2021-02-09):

/*
 * uv_led_driver.c
 *
 *  Created on: Mar 27, 2019
 *      Author: zaitldav
 */


#include "uv_led_driver.h"

/** @brief Initializes the LEDs
 *
 * This function initializes counters and sets pins and ports of LEDs
 * (Initialization of pins and ports MUST be done before using HAL).
 * This function sets LED counters to 0, and sets frequencies for LEDs.
 * This function sets all LEDs to enable.
 *
 * @param Void
 * @ return Void
 */
void uv_led_init( void )
{
	// bind the ports and pins to the arrays
	uv_led_ports[0] = UV_LED_0_GPIO_Port;
	uv_led_ports[1] = UV_LED_1_GPIO_Port;
	uv_led_ports[2] = UV_LED_2_GPIO_Port;
	uv_led_ports[3] = UV_LED_3_GPIO_Port;
	uv_led_ports[4] = UV_LED_4_GPIO_Port;
	uv_led_ports[5] = UV_LED_5_GPIO_Port;
	uv_led_ports[6] = UV_LED_6_GPIO_Port;
	uv_led_ports[7] = UV_LED_7_GPIO_Port;

	uv_led_pins[0] = UV_LED_0_Pin;
	uv_led_pins[1] = UV_LED_1_Pin;
	uv_led_pins[2] = UV_LED_2_Pin;
	uv_led_pins[3] = UV_LED_3_Pin;
	uv_led_pins[4] = UV_LED_4_Pin;
	uv_led_pins[5] = UV_LED_5_Pin;
	uv_led_pins[6] = UV_LED_6_Pin;
	uv_led_pins[7] = UV_LED_7_Pin;

	// UVLEDs global enable flag is disabled by default
	enable_global = 0;

	// Read setup from FLASH
	// Load uv_led_enabled values from FLASH
	uint32_t flash_address_enabled = FLASH_UVLEDS_ENABLED_ADDR;

	for(uint8_t i = 0; i < 8; i++)
	{
		uv_led_enabled[i] = *(uint16_t *)flash_address_enabled;
		flash_address_enabled += 2;
	}

	// Load uv_led_periods_ms values from FLASH
	uint32_t flash_address_periods = FLASH_UVLEDS_PERIODS_ADDR;

	for(uint8_t i = 0; i < 8; i++)
	{
		uv_led_periods_ms[i] = *(uint16_t *)flash_address_periods;
		flash_address_periods += 4;
	}

	// Reset the counters
	for (uint8_t i = 0; i < 8; i++)
	{
		uv_led_counter[i] = 0;
	}
}

/** @brief Sets period of the selected LED
 *
 *
 * @param led_id ID of the LED (0-7)
 * @param frequency frequency of the UV LED
 * @return 1 if success, otherwise 0
 */
uint8_t uv_led_set_frequency( uint8_t led_id, uint8_t frequency)
{
	// Check if the UVLED ID is valid
	if ((0 <= led_id) && (led_id < 8))
	{
		// Check if the frequency to be set is from valid range
		if ((UV_LED_FREQ_MIN <= frequency) && (frequency <= UV_LED_FREQ_MAX)) {
			// calculate the number of ticks needed to toggle the LED
			uint32_t period = (TIMER_FREQ/frequency)/2;
			uv_led_periods_ms[(uint8_t)led_id] = (uint32_t)period;
			uv_led_counter [(uint8_t)led_id] = 0;

			// Write the setup to the FLASH
			// Erase the FLASH Page with the periods
			HAL_FLASH_Unlock();
			FLASH_EraseInitTypeDef EraseInitStruct;
			uint32_t PAGEError = 0;
			EraseInitStruct.TypeErase   = FLASH_TYPEERASE_PAGES;
			EraseInitStruct.PageAddress = FLASH_UVLEDS_PERIODS_ADDR;
			EraseInitStruct.NbPages     = 1;
			HAL_FLASHEx_Erase(&EraseInitStruct, &PAGEError);
			CLEAR_BIT (FLASH->CR, (FLASH_CR_PER));
			HAL_FLASH_Lock();

			// Write to the USER FLASH
			HAL_FLASH_Unlock();
			uint32_t flashAddress = FLASH_UVLEDS_PERIODS_ADDR;
			for(int i = 0; i <8; i++)
			{
				HAL_FLASH_Program(FLASH_TYPEPROGRAM_WORD, flashAddress, uv_led_periods_ms[i]);
				flashAddress += 4;
			}
			CLEAR_BIT (FLASH->CR, (FLASH_CR_PG));
			HAL_FLASH_Lock();
			return 1;
		}
		return 0;
	}
	return 0;
}

/** @brief Enables selected LED
 *
 *
 * @param led_id ID of the LED (0-7)
 * @param enable 1 if the LED is enables, otherwise 0
 * @return 1 if success, otherwise 0
 */
uint8_t uv_led_enable(uint8_t led_id, uint8_t enable)
{
	// Check if the UVLED ID is valid
	if ((0 <= led_id) && (led_id < 8))
	{
		// Check if the value is valid
		if ((enable == 0) || (enable == 1))
		{
			uv_led_enabled[led_id] = enable;
			uv_led_counter [(uint8_t)led_id] = 0;
			HAL_GPIO_WritePin(uv_led_ports[led_id], uv_led_pins[led_id], enable);

			// Erase the USER FLASH
			HAL_FLASH_Unlock();
			FLASH_EraseInitTypeDef EraseInitStruct;
			uint32_t PAGEError = 0;
			EraseInitStruct.TypeErase   = FLASH_TYPEERASE_PAGES;
			EraseInitStruct.PageAddress = FLASH_UVLEDS_ENABLED_ADDR;
			EraseInitStruct.NbPages     = 1;
			HAL_FLASHEx_Erase(&EraseInitStruct, &PAGEError);
			CLEAR_BIT (FLASH->CR, (FLASH_CR_PER));
			HAL_FLASH_Lock();

			// Write to the USER FLASH
			HAL_FLASH_Unlock();
			uint32_t flashAddress = FLASH_UVLEDS_ENABLED_ADDR;
			for(int i = 0; i <8; i++)
			{
				HAL_FLASH_Program(FLASH_TYPEPROGRAM_HALFWORD, flashAddress, uv_led_enabled[i]);
				flashAddress += 2;
			}
			CLEAR_BIT (FLASH->CR, (FLASH_CR_PG));
			HAL_FLASH_Lock();
			return 1;
		}
		return 0;
	}
	return 0;
}

/** @brief Toggles the selected LED
 * 	This is a simple wrapper for HAL_GPIO_TogglePin. If the LED is enabled, toggles the LED with selected id.
 *
 * 	@param led_id ID of the LED to be toggled
 * 	@return Void
 */
void uv_led_toggle(uint8_t led_id)
{
		if ((uv_led_enabled[led_id]))
		{
			HAL_GPIO_WritePin(uv_led_ports[led_id], uv_led_pins[led_id], !HAL_GPIO_ReadPin(uv_led_ports[led_id], uv_led_pins[led_id]) && enable_global);
		}
}

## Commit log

2021-02-09 Added UVDAR Module PCB and Firmware.
    [Power_Sources.sch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]
2021-02-10 Added UVDAR Standalone.
    [Power_Sources.sch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]
2021-02-22 Created (and tested) firmware for standalone UVDAR PCB.

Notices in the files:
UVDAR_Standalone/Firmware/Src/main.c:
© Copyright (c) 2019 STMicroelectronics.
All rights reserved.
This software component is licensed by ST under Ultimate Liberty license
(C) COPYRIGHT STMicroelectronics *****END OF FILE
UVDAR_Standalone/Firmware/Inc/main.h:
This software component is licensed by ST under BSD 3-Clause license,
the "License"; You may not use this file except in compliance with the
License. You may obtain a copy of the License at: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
